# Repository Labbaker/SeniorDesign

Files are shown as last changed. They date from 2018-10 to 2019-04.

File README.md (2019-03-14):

# SeniorDesign
Checklist of things to do:

Main Station Software:
main page: beacon map, view emergency alerts, sidebar w/ new alerts (all pages have back to main menu option)
Map view of beacons - map of the tucson area with icons for each beacon, (gps coords on mouseover? ping on mouseover?) displays if alert triggered or repair needed.
Emergency alerts page: new displayed, resolved on different page
-resolved page: data abt alert
when viewing new alert, text box for message + ack
yes/no for resolving alert

backend stuff: 
Xbee connection - receive GPS data from beacons
XBee connection - get alerts from beacons after the beacons get them from the app
XBee - send ack + message to alert device
Interface with MySQL database?!?! PHP database!?!?!?
pings beacons every hour

Mobile Application:
Main page: buttons for emergencies options, map, "about app" and (about me") - each of these pages has a link back to the main page
About app: just text
map view: pre downloaded map of tucson that will get the user's GPS location and display their location on the map, 
or text that says "outside bounds" if their location ins't on the map. If the phones gps isn't working, get the gpd coords of the nearet
beacon and draw a circle of 20m around that point that says "you're within this circle"
Emergency options: 3 buttons for 3 levels of emergency, yes/no confirm after. 
- these have 4 states: no yes/no (fine), yes, no, no yes/no (not fine) (if rest is finished, add optional text box)
ack screen: "sending" (after hitting button) "sending..." (ack from beacon). (send) ack from main station (text), reset button 
(display note from main station)
About me: (optional) ICE info (medical conditions, contact info)

Beacon Software:
GPS connection: get the beacon's gps, save it. get new coords once every 24 hours, gps should sleep
bluetooth/mobile app: 
(according to adafruit tutorial) broadcasts a char string that mobile app bluetooth looks for
send GPS coords if mobile app requests it for map. 
transmit all the stuff related to alerts/ack'ing them
responds to main station ping every hour

Connections:
Mobile app -> Beacon
Initial Bluetooth connection
Emergency commands
GPS request

Beacon -> Mobile App
Initial Bluetooth connection
Emergency command ack
GPS

Beacon -> Beacon
Mesh Network
Passing GPS
emergency alerts

Beacon -> main station
mesh network connection
ack w/ time and GPS
emergency alerts

main station -> beacon
mesh network
ping request
emergency alert ack w/ note

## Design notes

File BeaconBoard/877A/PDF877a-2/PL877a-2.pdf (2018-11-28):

Linear Technology Corporation
LTC3531ES6-3.3
Parts List | DC877A Rev 2
Item | Qty | Ref - Des | Desc | Manufacturer's Part Number
1 | 2 | C1,C2 | CAP, 0805 22uF 20% 6.3V X5R | TDK C2012X5R0J226M
2 | 1 | C3 | CAP, 0603 1uF 20% 6.3V X5R | AVX 06036D105MAT
3 | 0 | D2 | DIODE, SCHOTTKY BARRIER OPTION | PHILIPS PMEG2010EA OPTION
4 | 1 | JP1 | HEADER,3 PINS 2mm | COMM CON 2802S-03G2
5 | 1 | L1 | INDUCTOR, 10uH | SUMIDA CDRH3D16/HP-100
6 | 1 | R1 | RES, 0402 1M OHMS 5% 1/16W | AAC CR05-105JM
7 | 4 | TP1,TP2,TP3,TP4 | TURRET | MILL MAX2501-2
8 | 1 | U1 | IC, LTC3531ES6-3.3 | LINEAR TECH LTC3531ES6-3.3
9 | 1 | JP1 | SHUNT | COMM CON CCIJ2MM-138G

### 1 of 1

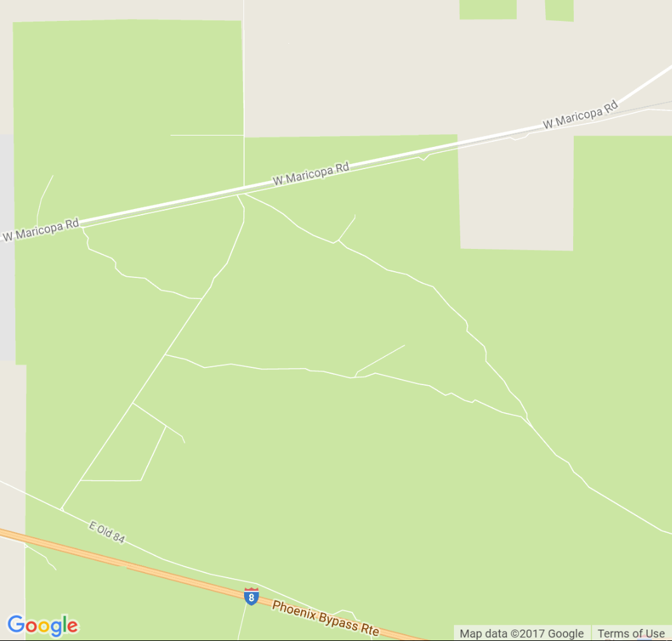
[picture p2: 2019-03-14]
MainStationSoftware/map.png

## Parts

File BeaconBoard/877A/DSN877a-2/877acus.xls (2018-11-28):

Item | Qty | Ref - Des | Desc | Manufacturer's Part Number
 |  | REQUIRED CIRCUIT COMPONENTS:
1 | 2 | C1,C2 | CAP, 0805 22uF 20% 6.3V X5R | TDK C2012X5R0J226M
5 | 1 | L1 | INDUCTOR, 10uH | SUMIDA CDRH3D16/HP-100
8 | 1 | U1 | IC, LTC3531ES6-3.3 | LINEAR TECH LTC3531ES6-3.3
 |  | ADDITIONAL DEMO BOARD CIRCUIT COMPONENTS:
2 | 1 | C3 | CAP, 0603 1uF 20% 6.3V X5R | AVX 06036D105MAT
3 | 0 | D2 | DIODE, SCHOTTKY BARRIER OPTION | PHILIPS PMEG2010EA OPTION
6 | 1 | R1 | RES, 0402 1M OHMS 5% 1/16W | AAC CR05-105JM

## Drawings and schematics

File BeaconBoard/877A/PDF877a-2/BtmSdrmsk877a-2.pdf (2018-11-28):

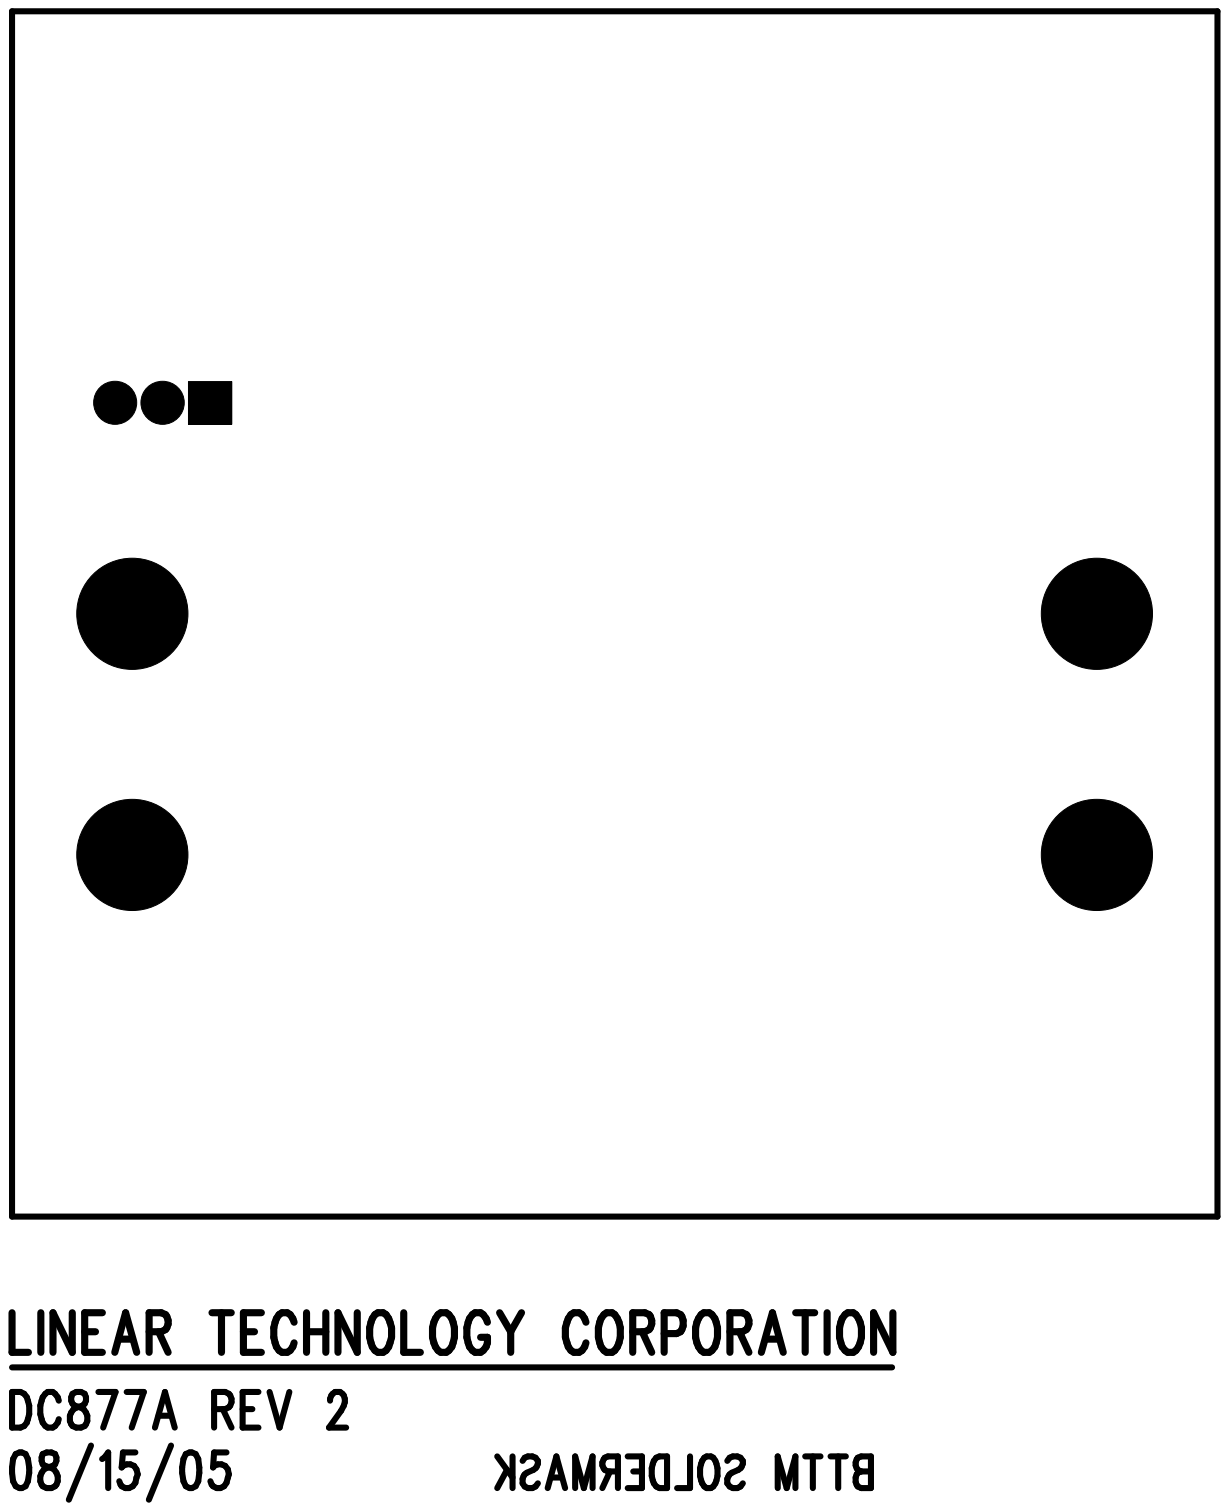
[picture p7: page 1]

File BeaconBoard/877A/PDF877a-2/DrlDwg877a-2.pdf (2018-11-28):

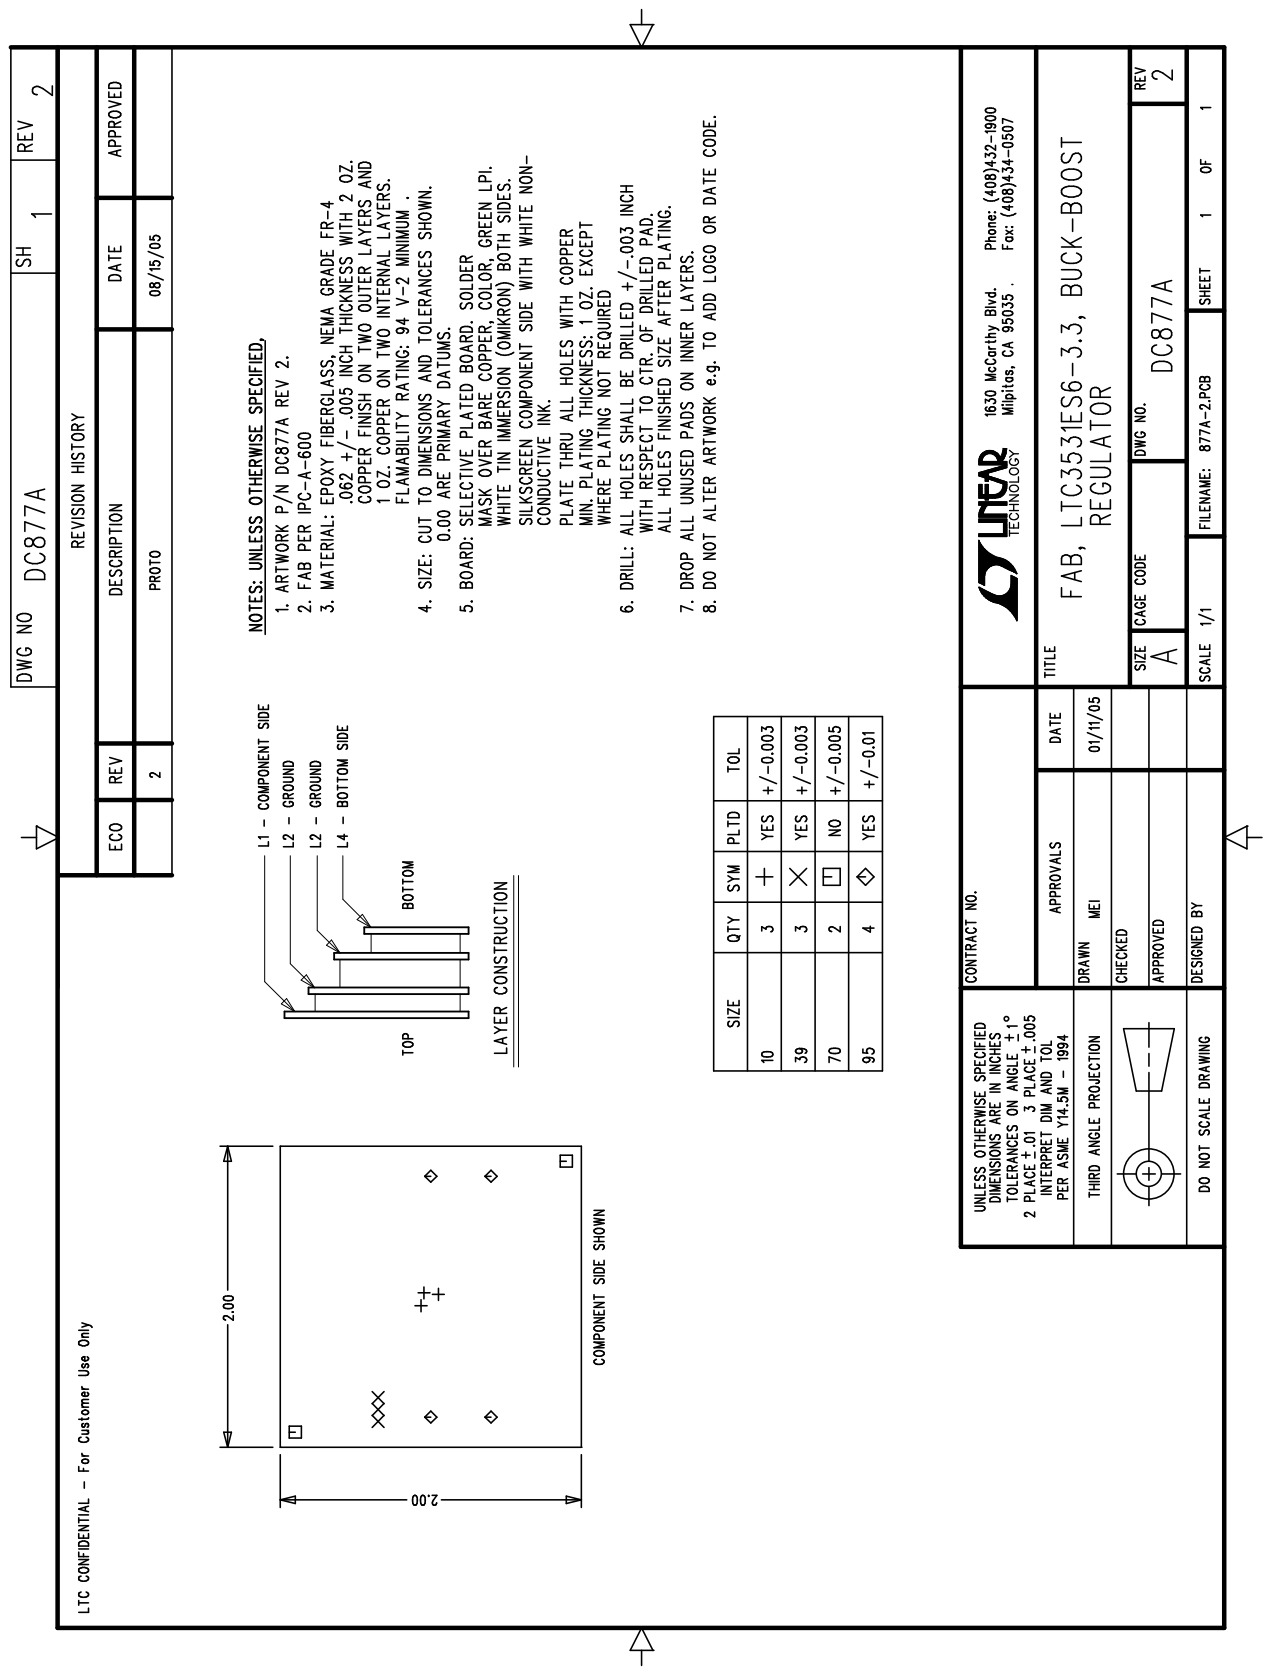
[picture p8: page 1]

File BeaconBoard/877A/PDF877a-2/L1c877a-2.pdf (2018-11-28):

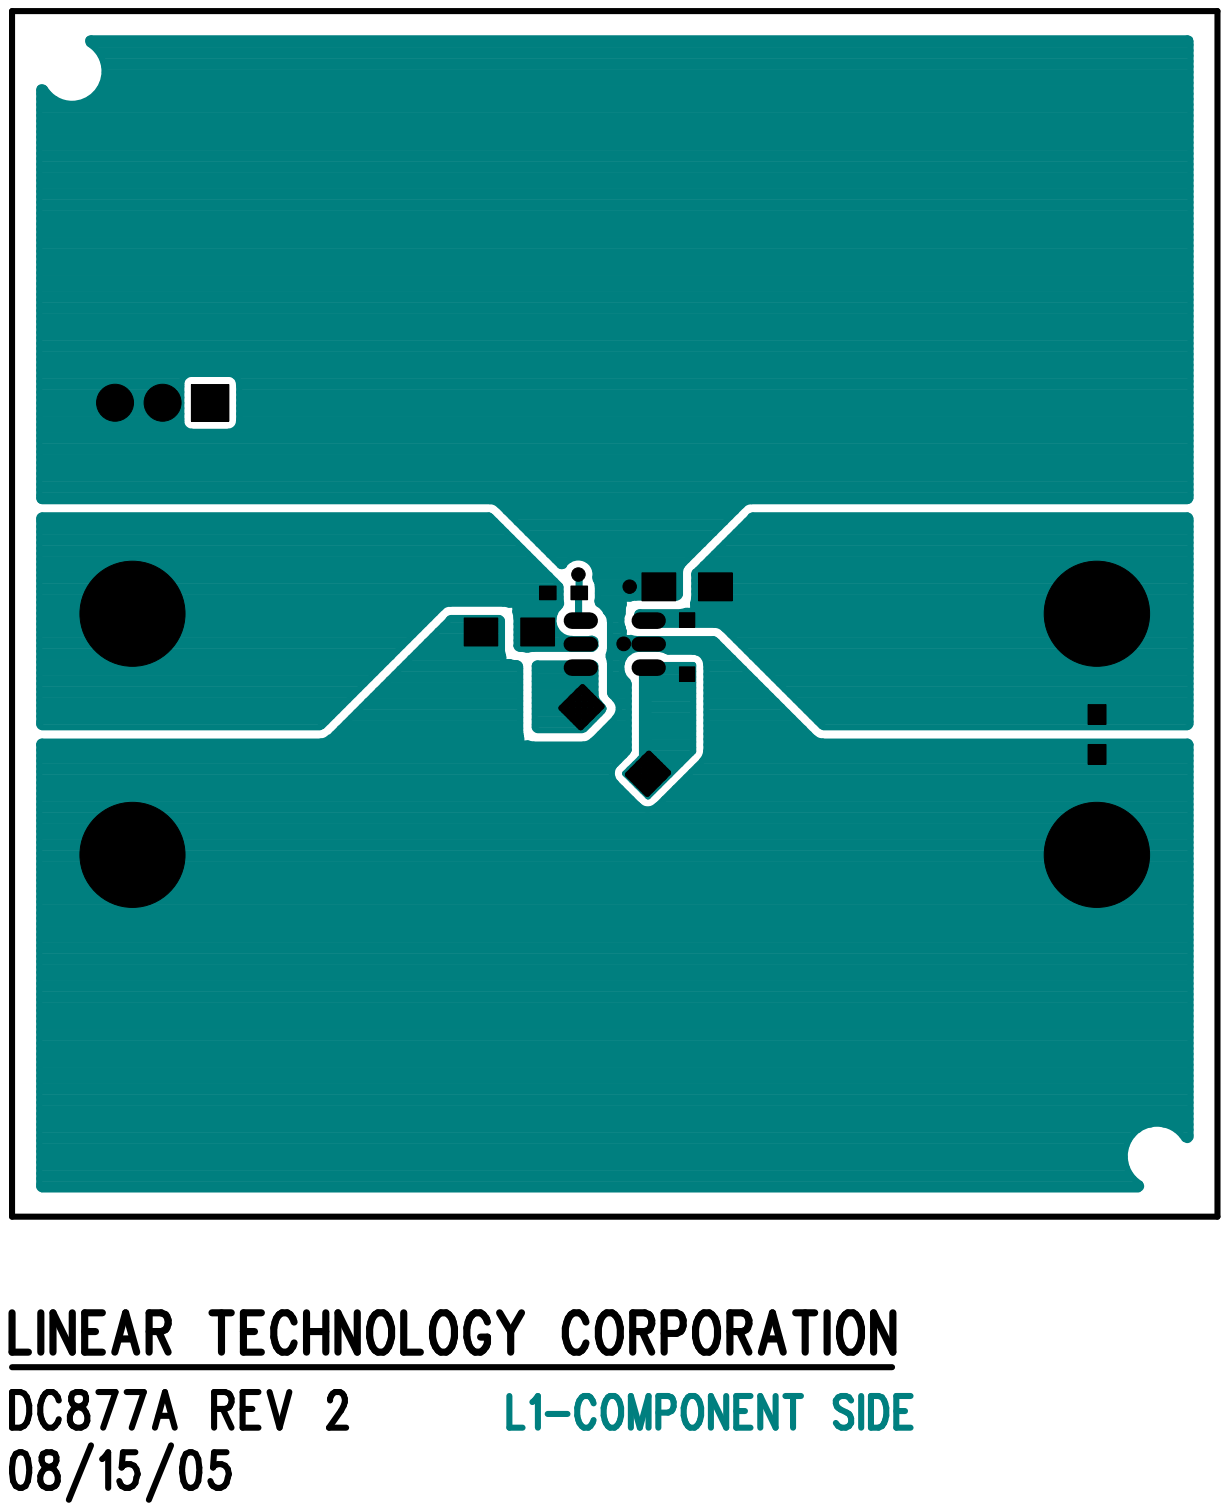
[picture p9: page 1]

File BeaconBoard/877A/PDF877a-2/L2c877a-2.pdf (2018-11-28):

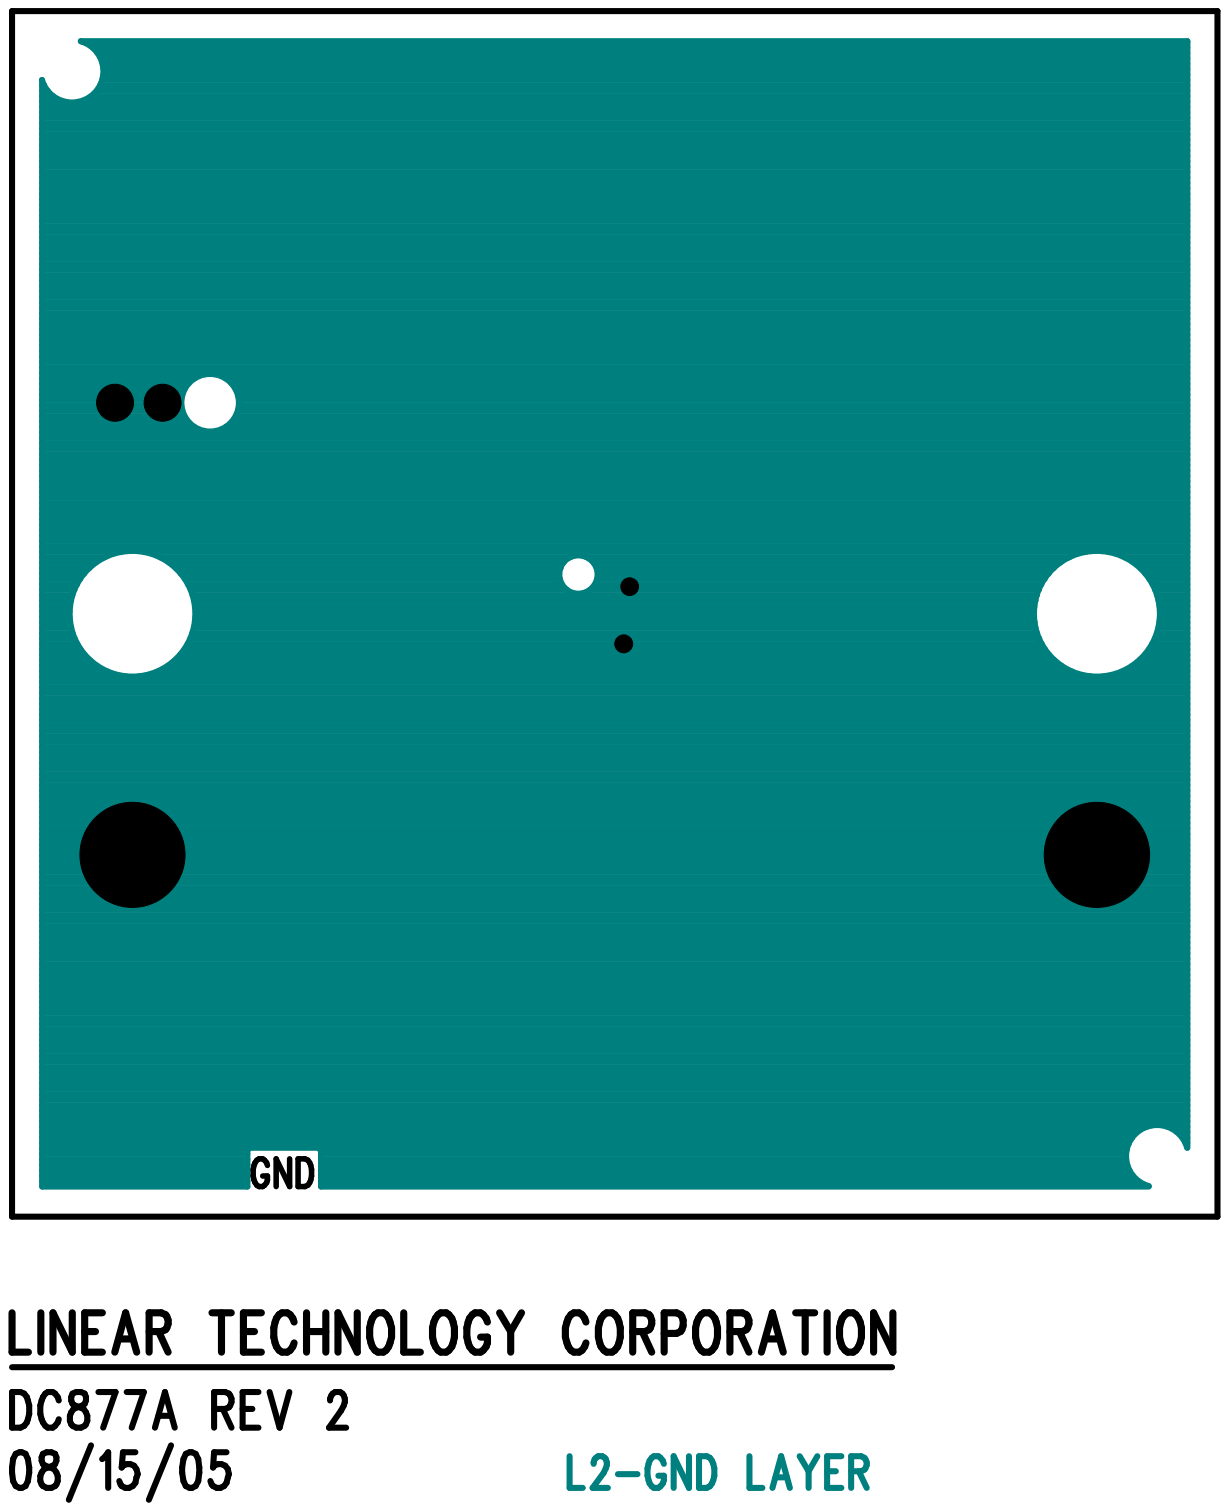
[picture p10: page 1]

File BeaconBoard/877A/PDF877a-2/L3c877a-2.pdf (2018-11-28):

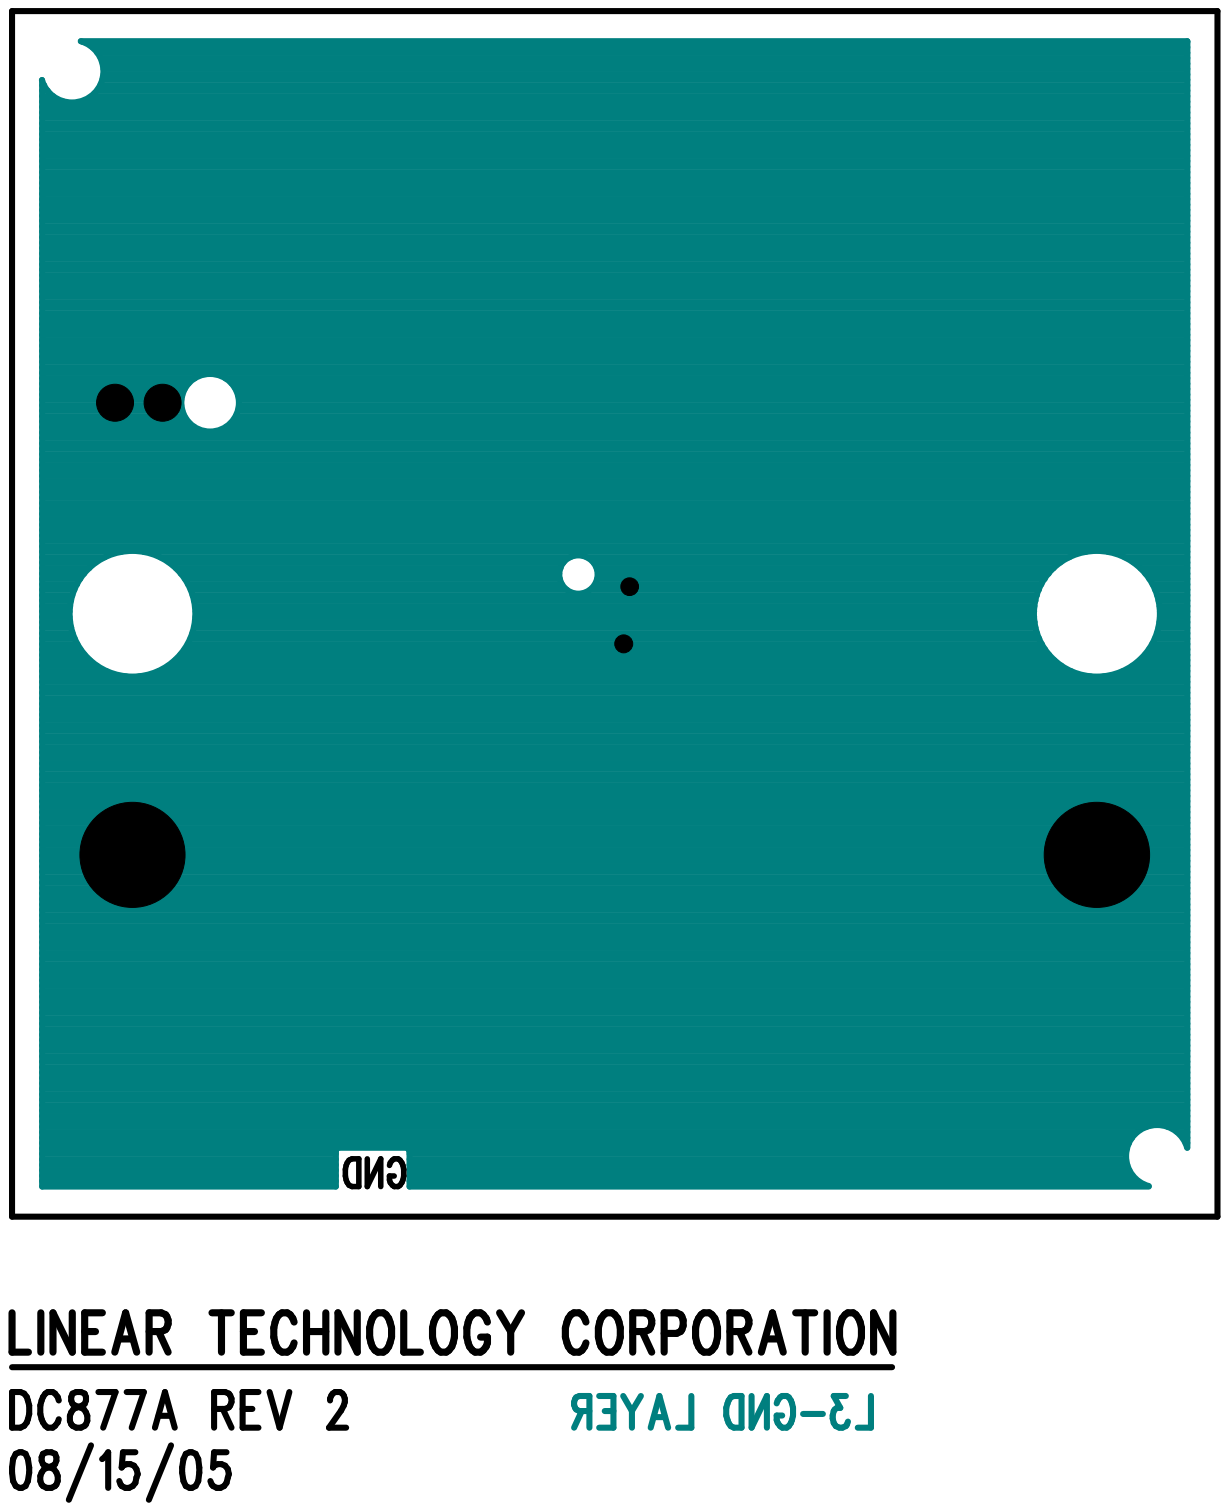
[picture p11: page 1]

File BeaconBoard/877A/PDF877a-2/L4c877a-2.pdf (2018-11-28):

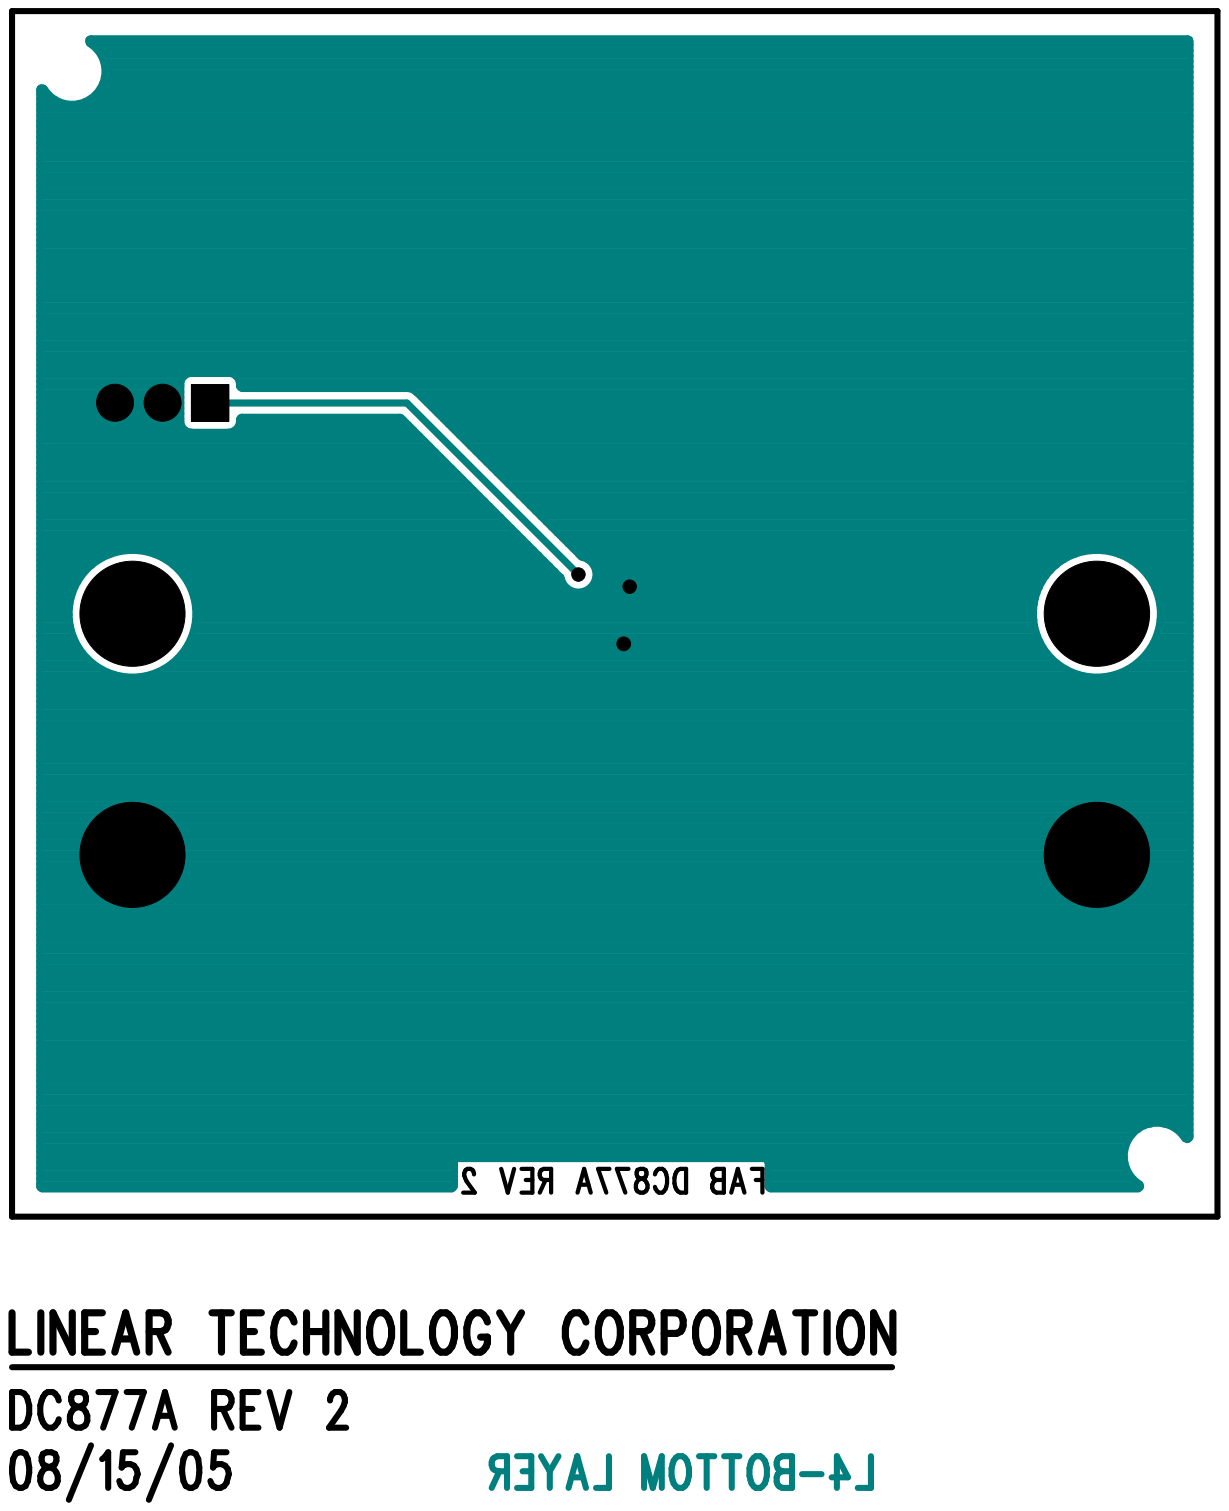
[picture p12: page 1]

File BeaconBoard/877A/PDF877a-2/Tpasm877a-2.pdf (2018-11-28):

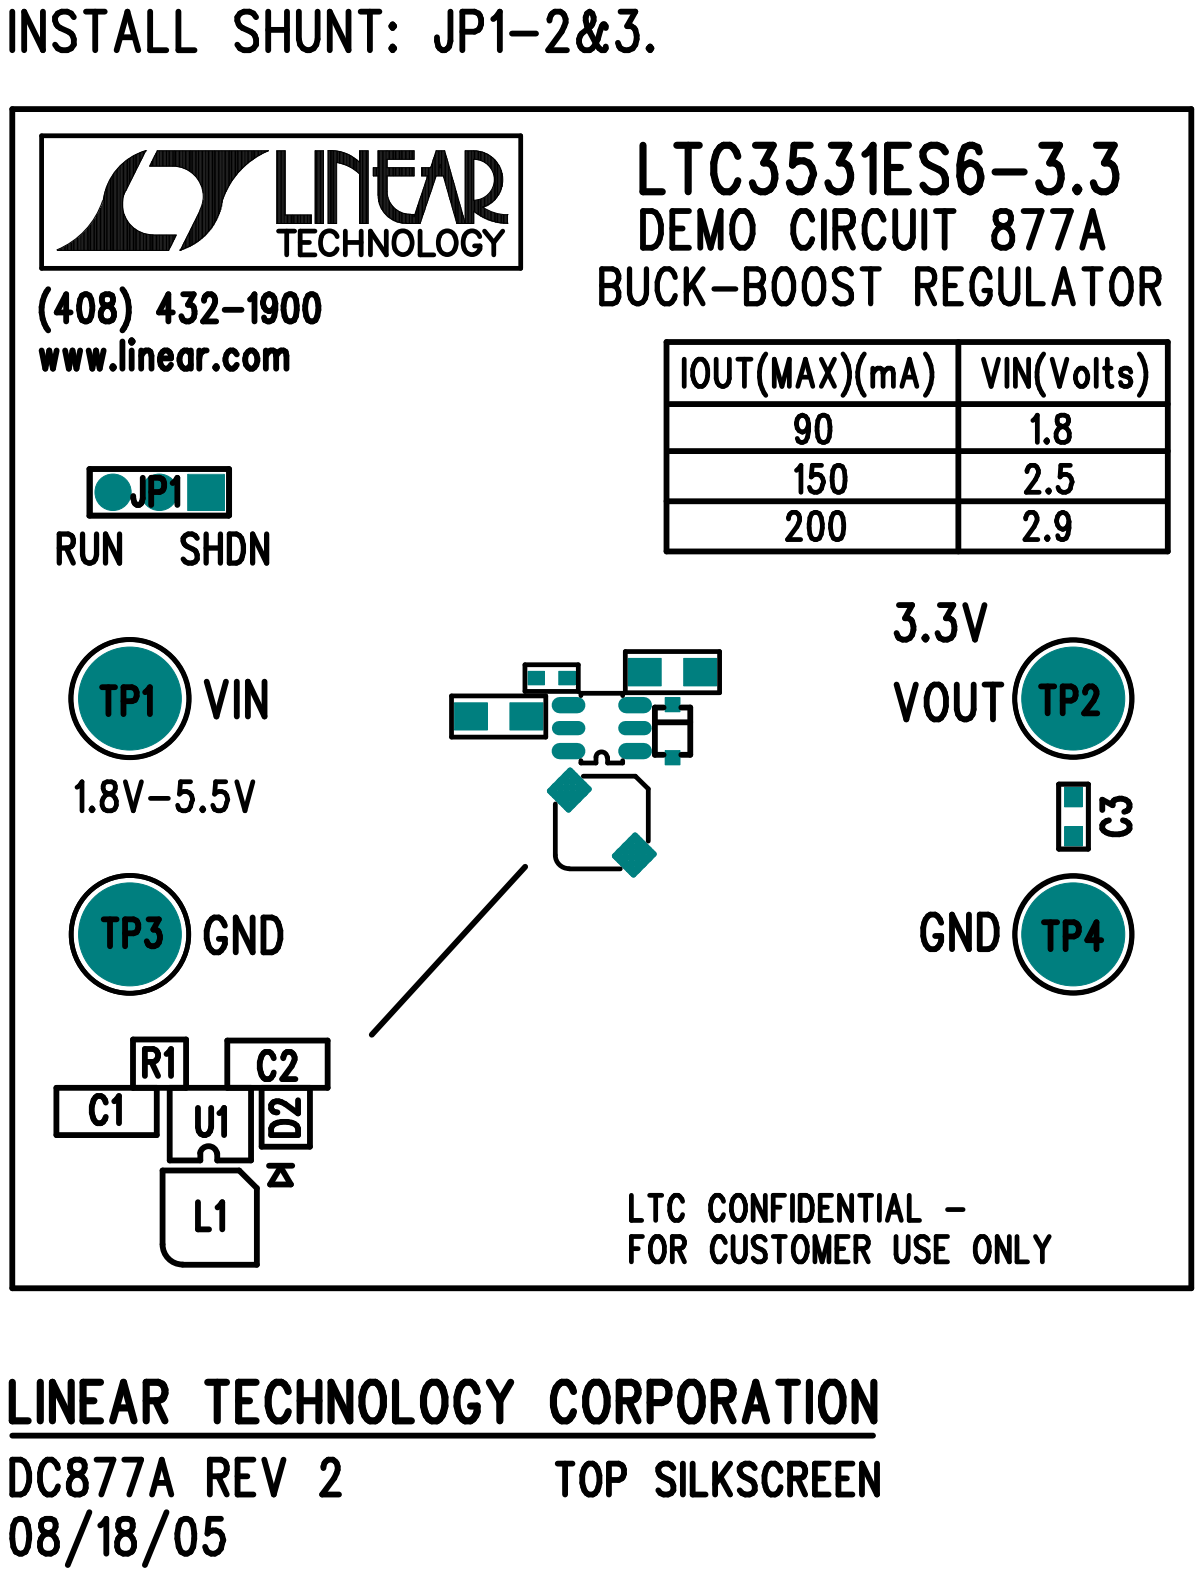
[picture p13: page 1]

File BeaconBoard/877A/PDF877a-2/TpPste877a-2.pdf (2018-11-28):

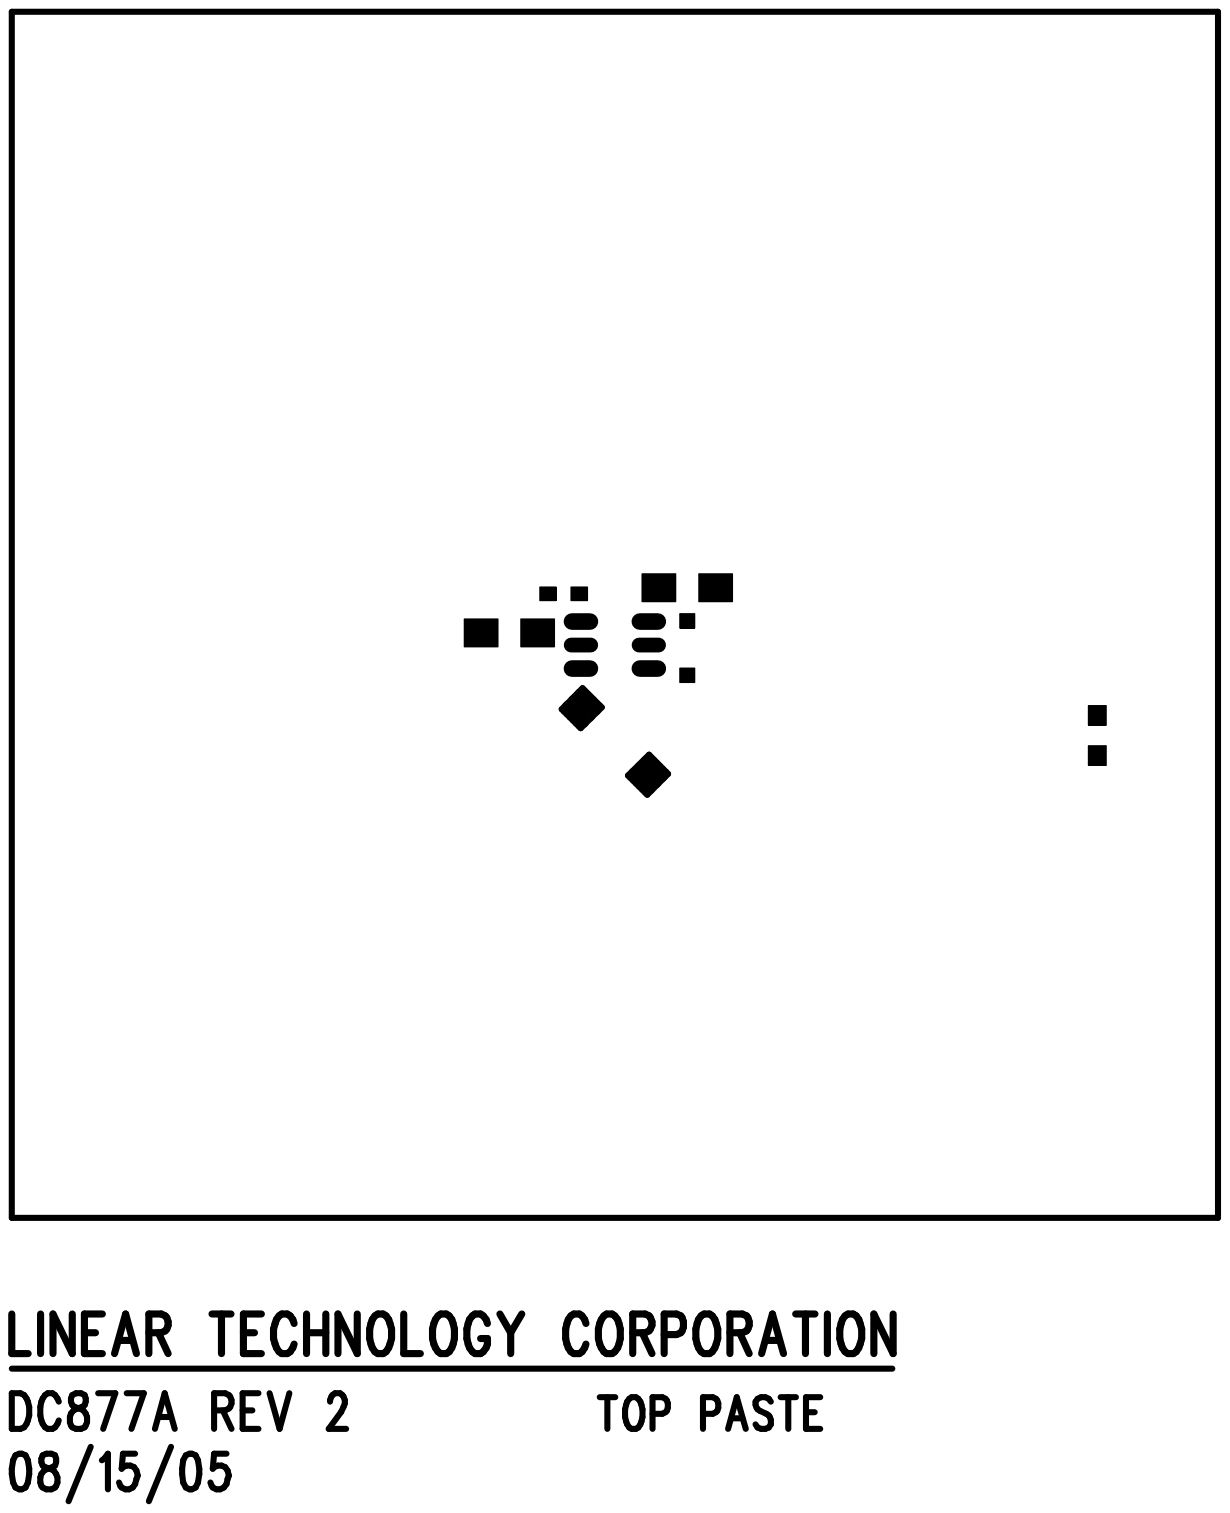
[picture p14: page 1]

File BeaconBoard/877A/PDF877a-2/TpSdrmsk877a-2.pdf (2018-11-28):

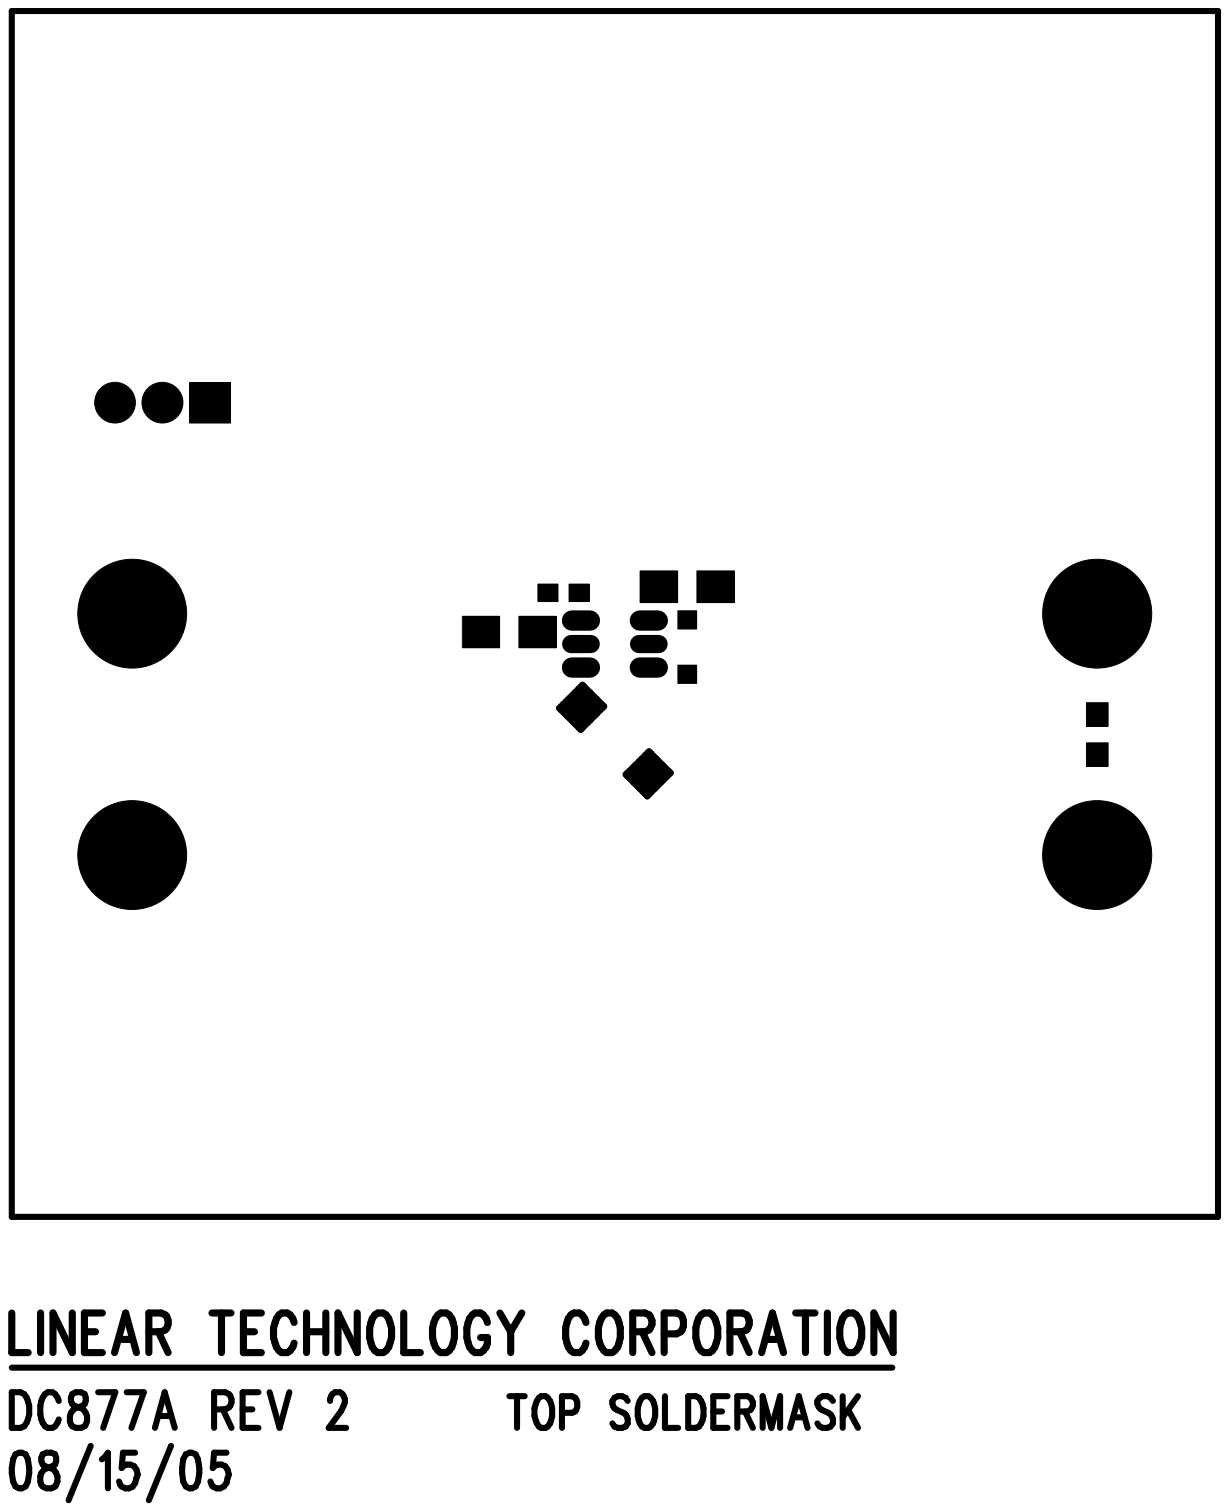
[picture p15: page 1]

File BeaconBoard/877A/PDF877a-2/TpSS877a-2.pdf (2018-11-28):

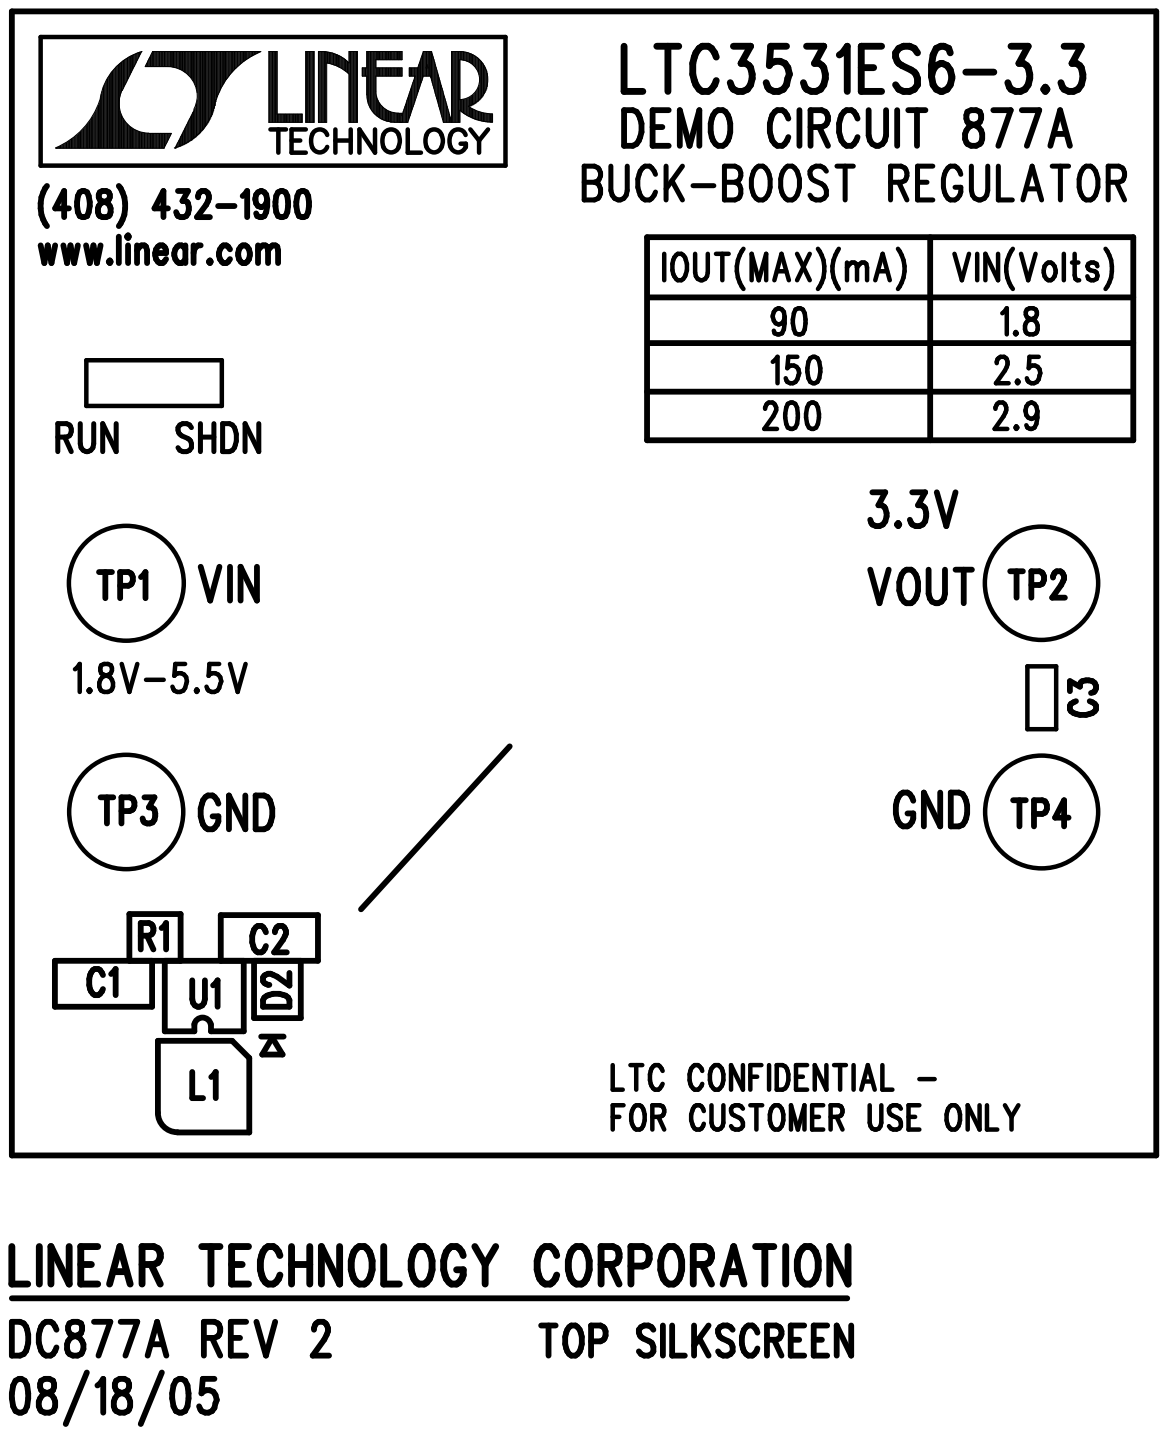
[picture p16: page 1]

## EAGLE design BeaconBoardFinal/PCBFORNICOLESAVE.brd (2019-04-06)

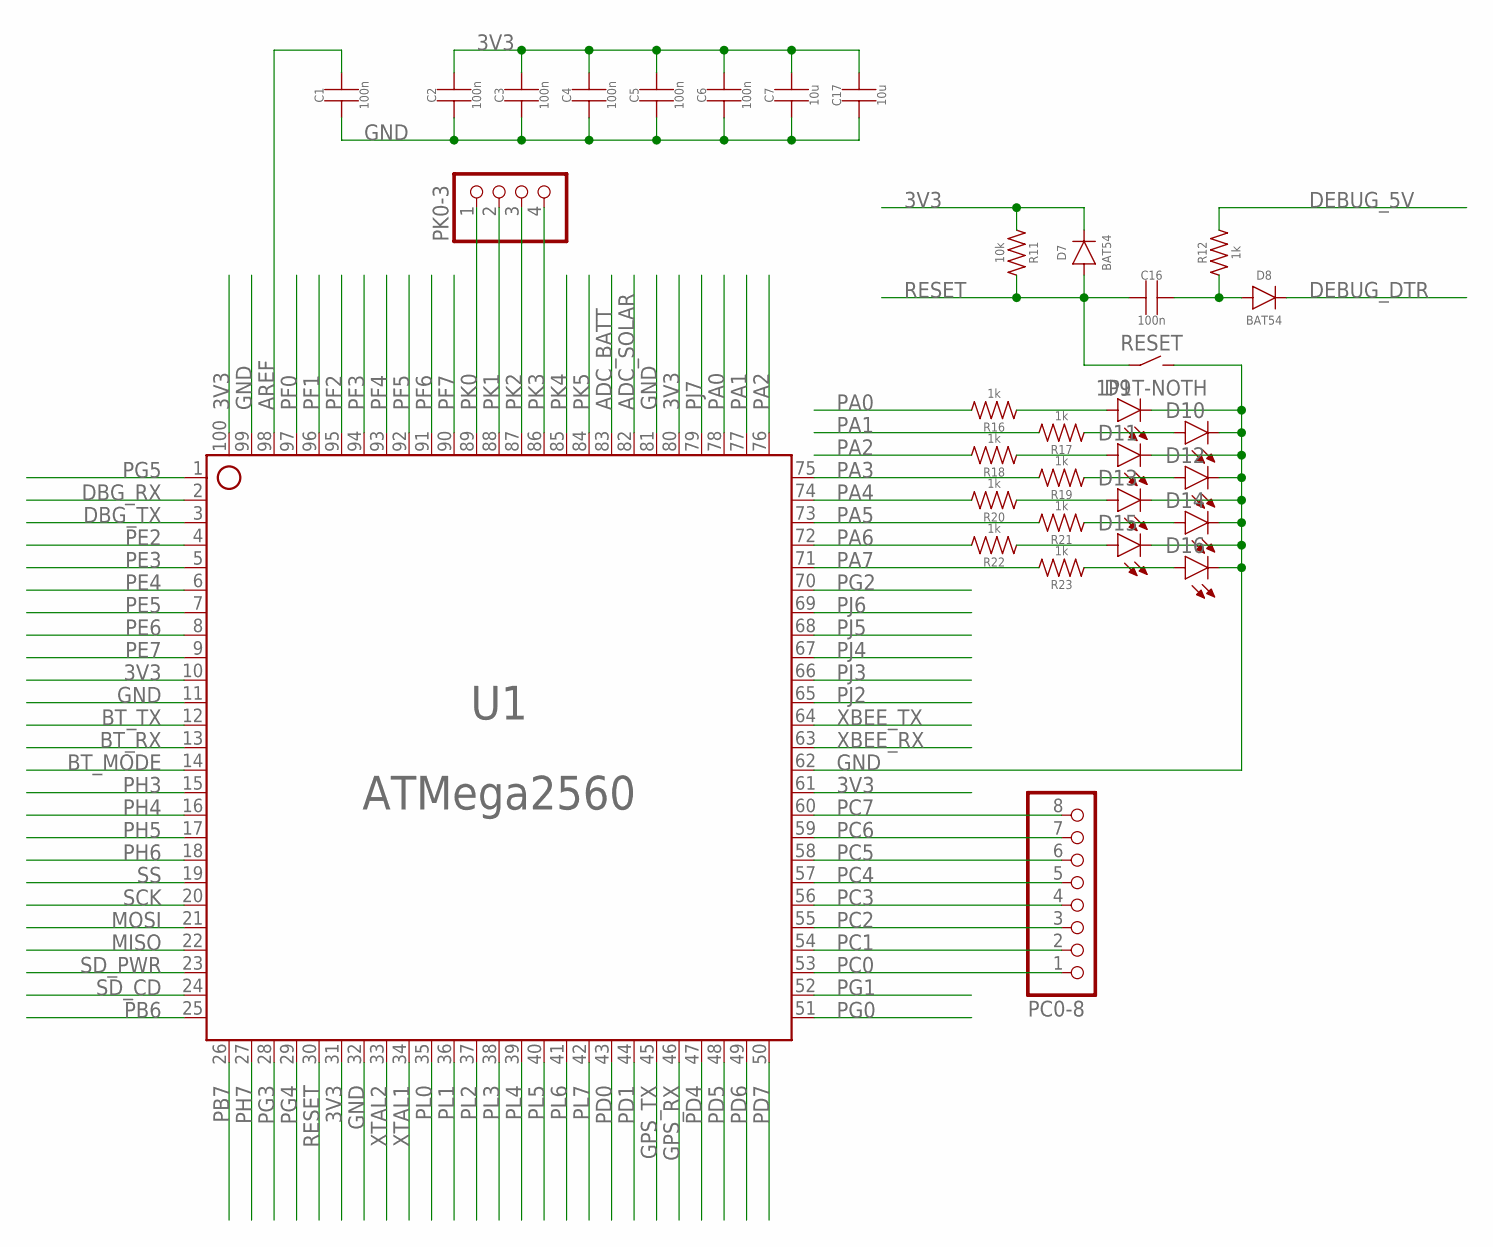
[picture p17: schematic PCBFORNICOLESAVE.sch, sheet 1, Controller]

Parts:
C1, C2, C3, C4, C5, C6, C16: 100n; 0603
C7, C17: 10u; 1206
D7, D8: BAT54; SOD323
D9, D10, D11, D12, D13, D14, D15, D16: LED1206; 1206
PC0-8: PINHD-1X82MM; 1X08_2MM
PK0-3: PINHD-1X42MM; 1X04_2MM
R11: 10k; 0603
R12, R16, R17, R18, R19, R20, R21, R22, R23: 1k; 0603
RESET: 1P1T-NOTH; 6X6MM-TH
U1: ATMega2560; 100QFP

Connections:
3V3: C2.1, C3.1, C4.1, C5.1, C6.1, C7.1, C17.1, D7.2 (C), R11.2, U1.10, U1.31, U1.61, U1.80, U1.100; also elsewhere on the board
ADC_BATT: U1.83; also elsewhere on the board
ADC_SOLAR: U1.82; also elsewhere on the board
AREF: C1.1, U1.98
BT_MODE: U1.14; also elsewhere on the board
BT_RX: U1.13; also elsewhere on the board
BT_TX: U1.12; also elsewhere on the board
DBG_RX: U1.2; also elsewhere on the board
DBG_TX: U1.3; also elsewhere on the board
DEBUG_5V: R12.1; also elsewhere on the board
DEBUG_DTR: D8.2 (C); also elsewhere on the board
GND: C1.2, C2.2, C3.2, C4.2, C5.2, C6.2, C7.2, C17.2, D9.2 (C), D10.2 (C), D11.2 (C), D12.2 (C), D13.2 (C), D14.2 (C), D15.2 (C), D16.2 (C), RESET.3 (A1), RESET.4 (A1), U1.11, U1.32, U1.62, U1.81, U1.99; also elsewhere on the board
GPS_RX: U1.46; also elsewhere on the board
GPS_TX: U1.45; also elsewhere on the board
MISO: U1.22; also elsewhere on the board
MOSI: U1.21; also elsewhere on the board
unnamed: C16.1, D8.1 (A), R12.2
unnamed: D9.1 (A), R16.2
unnamed: D10.1 (A), R17.2
unnamed: D11.1 (A), R18.2
unnamed: D12.1 (A), R19.2
unnamed: D13.1 (A), R20.2
unnamed: D14.1 (A), R21.2
unnamed: D15.1 (A), R22.2
unnamed: D16.1 (A), R23.2
PA0: R16.1, U1.78
PA1: R17.1, U1.77
PA2: R18.1, U1.76
PA3: R19.1, U1.75
PA4: R20.1, U1.74
PA5: R21.1, U1.73
PA6: R22.1, U1.72
PA7: R23.1, U1.71
PB6: U1.25
PB7: U1.26
PC0: PC0-8.1, U1.53
PC1: PC0-8.2, U1.54
PC2: PC0-8.3, U1.55
PC3: PC0-8.4, U1.56
PC4: PC0-8.5, U1.57
PC5: PC0-8.6, U1.58
PC6: PC0-8.7, U1.59
PC7: PC0-8.8, U1.60
PD0: U1.43
PD1: U1.44
PD4: U1.47
PD5: U1.48
PD6: U1.49
PD7: U1.50
PE2: U1.4
PE3: U1.5
PE4: U1.6
PE5: U1.7
PE6: U1.8
PE7: U1.9
PF0: U1.97
PF1: U1.96
PF2: U1.95
PF3: U1.94
PF4: U1.93
PF5: U1.92
PF6: U1.91
PF7: U1.90
PG0: U1.51
PG1: U1.52
PG2: U1.70
PG3: U1.28
PG4: U1.29
PG5: U1.1
PH3: U1.15
PH4: U1.16
PH5: U1.17
PH6: U1.18
PH7: U1.27
PJ2: U1.65
PJ3: U1.66
PJ4: U1.67
PJ5: U1.68
PJ6: U1.69
PJ7: U1.79
PK0: PK0-3.1, U1.89
PK1: PK0-3.2, U1.88
PK2: PK0-3.3, U1.87
PK3: PK0-3.4, U1.86
PK4: U1.85
PK5: U1.84
PL0: U1.35
PL1: U1.36
PL2: U1.37
PL3: U1.38
PL4: U1.39
PL5: U1.40
PL6: U1.41
PL7: U1.42
RESET: C16.2, D7.1 (A), R11.1, RESET.1, RESET.2 (P1), U1.30; also elsewhere on the board
SCK: U1.20; also elsewhere on the board
SD_CD: U1.24; also elsewhere on the board
SD_PWR: U1.23; also elsewhere on the board
SS: U1.19; also elsewhere on the board
XBEE_RX: U1.63; also elsewhere on the board
XBEE_TX: U1.64; also elsewhere on the board
XTAL1: U1.34
XTAL2: U1.33

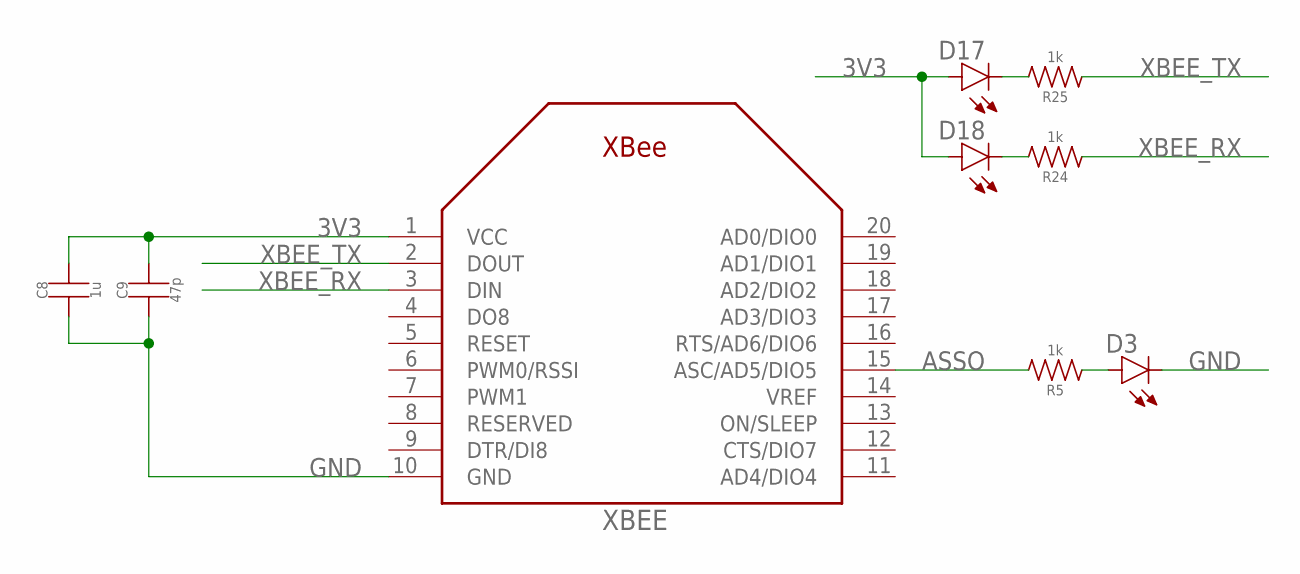
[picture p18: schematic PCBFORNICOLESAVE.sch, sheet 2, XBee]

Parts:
C8: 1u; 0603
C9: 47p; 0603
D3, D17, D18: LED1206; 1206
R5, R24, R25: 1k; 0603
XBEE: XBEE

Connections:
3V3: C8.1, C9.1, D17.1 (A), D18.1 (A), XBEE.1 (VCC); also elsewhere on the board
ASSO: R5.1, XBEE.15 (ASC/AD5/DIO5)
GND: C8.2, C9.2, D3.2 (C), XBEE.10 (GND); also elsewhere on the board
unnamed: D3.1 (A), R5.2
unnamed: D17.2 (C), R25.1
unnamed: D18.2 (C), R24.1
XBEE_RX: R24.2, XBEE.3 (DIN); also elsewhere on the board
XBEE_TX: R25.2, XBEE.2 (DOUT); also elsewhere on the board

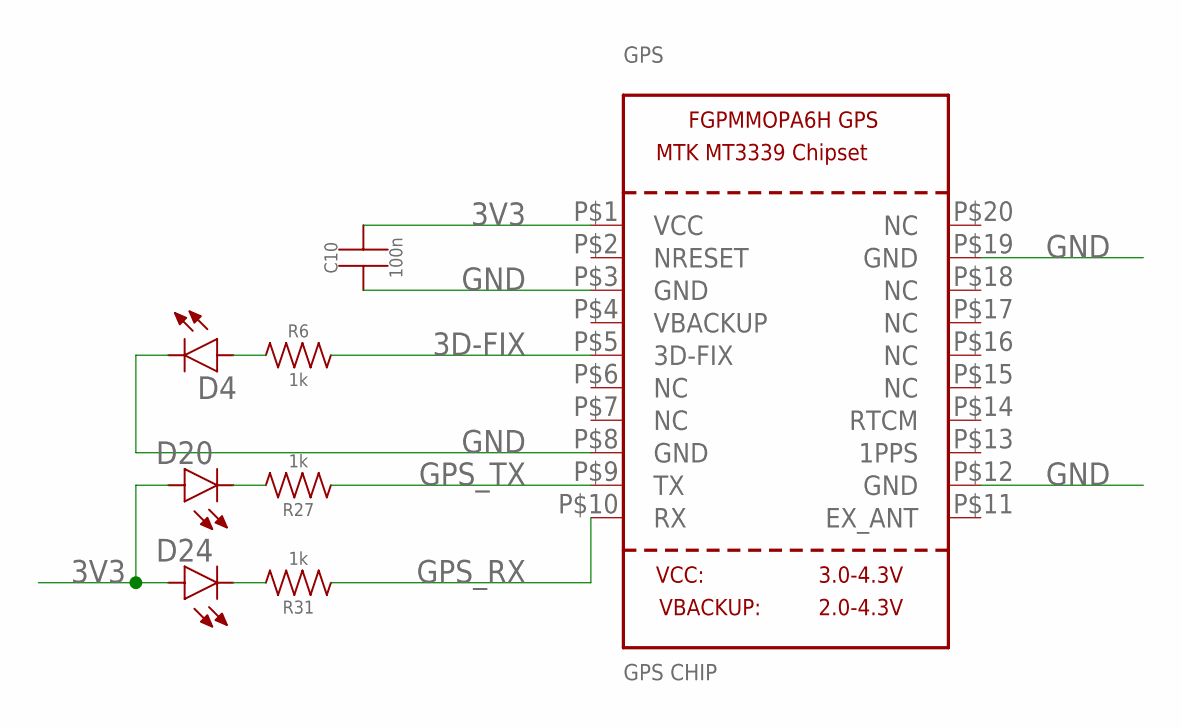
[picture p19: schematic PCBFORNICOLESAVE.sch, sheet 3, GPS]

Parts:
C10: 100n; 0603
D4, D20, D24: LED1206; 1206
GPS: GPS CHIP; FGPMMOPA6H
R6, R27, R31: 1k; 0603

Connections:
3D-FIX: GPS.P$5 (3D-FIX), R6.1
3V3: C10.1, D20.1 (A), D24.1 (A), GPS.P$1 (VCC); also elsewhere on the board
GND: C10.2, D4.2 (C), GPS.P$3 (GND), GPS.P$8 (GND), GPS.P$12 (GND), GPS.P$19 (GND); also elsewhere on the board
GPS_RX: GPS.P$10 (RX), R31.2; also elsewhere on the board
GPS_TX: GPS.P$9 (TX), R27.2; also elsewhere on the board
unnamed: D4.1 (A), R6.2
unnamed: D20.2 (C), R27.1
unnamed: D24.2 (C), R31.1

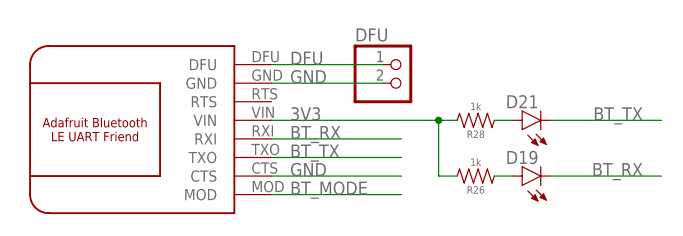
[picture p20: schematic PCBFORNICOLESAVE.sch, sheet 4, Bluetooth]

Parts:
BT: ADAFRUIT_BLUETOOTH_LE_UART_FRIEND
D19, D21: LED1206; 1206
DFU: PINHD-1X2""; 1X02
R26, R28: 1k; 0603

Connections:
3V3: BT.VIN, R26.1, R28.1; also elsewhere on the board
BT_MODE: BT.MOD; also elsewhere on the board
BT_RX: BT.RXI, D19.2 (C); also elsewhere on the board
BT_TX: BT.TXO, D21.2 (C); also elsewhere on the board
DFU: BT.DFU, DFU.1
GND: BT.CTS, BT.GND, DFU.2; also elsewhere on the board
unnamed: D21.1 (A), R28.2
unnamed: D19.1 (A), R26.2

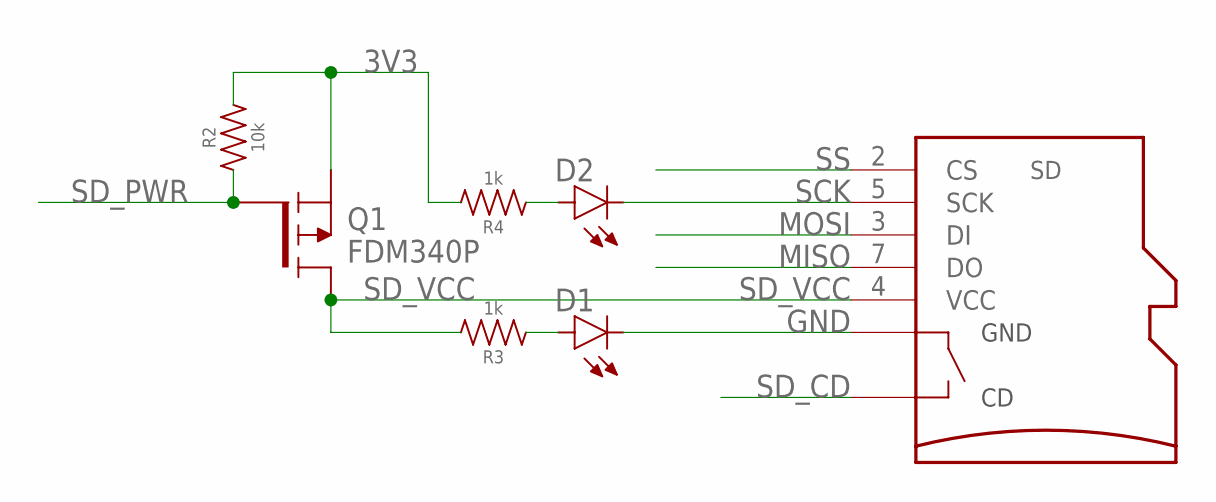
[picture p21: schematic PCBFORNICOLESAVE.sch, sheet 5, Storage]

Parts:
D1, D2: LED1206; 1206
Q1: FDM340P; SOT23-3
R2: 10k; 0603
R3, R4: 1k; 0603
SD: MICROSDFRONT; USD,FRONT

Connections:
3V3: Q1.3 (S), R2.1, R4.1; also elsewhere on the board
GND: D1.2 (C), SD.1 (GND), SD.6 (GND), SD.8 (GND), SD.S0 (GND), SD.S1 (GND), SD.S2 (GND), SD.S3 (GND); also elsewhere on the board
MISO: SD.7 (DO); also elsewhere on the board
MOSI: SD.3 (DI); also elsewhere on the board
unnamed: D1.1 (A), R3.2
unnamed: D2.1 (A), R4.2
SCK: D2.2 (C), SD.5 (SCK); also elsewhere on the board
SD_CD: SD.SW (CD); also elsewhere on the board
SD_PWR: Q1.1 (G), R2.2; also elsewhere on the board
SD_VCC: Q1.5 (D), R3.1, SD.4 (VCC)
SS: SD.2 (CS); also elsewhere on the board

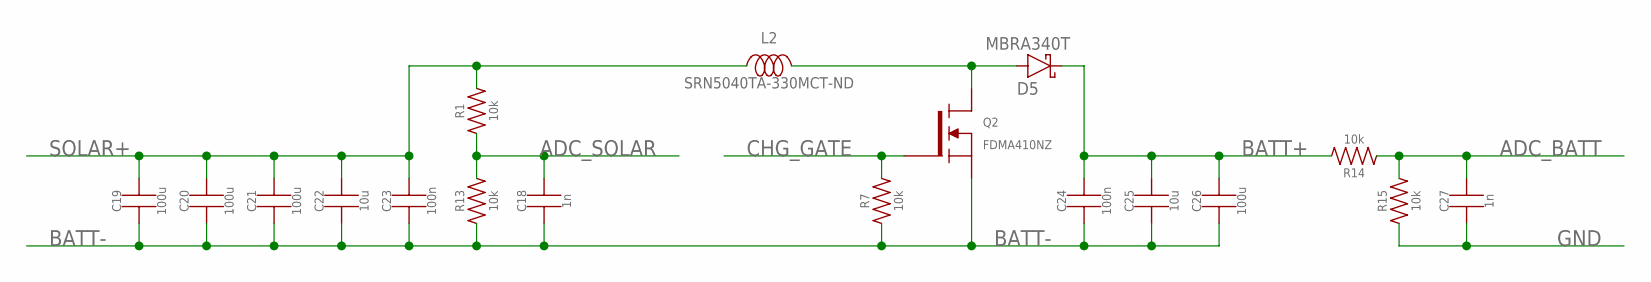
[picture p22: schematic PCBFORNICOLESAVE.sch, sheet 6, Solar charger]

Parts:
C18, C27: 1n; 0603
C19, C20, C21, C26: 100u; 1206
C22, C25: 10u; 1206
C23, C24: 100n; 0603
D5: MBRA340T; DO214AC
L2: SRN5040TA-330MCT-ND; 2020
Q2: FDMA410NZ; WDFN-6
R1, R7, R13, R14, R15: 10k; 0603

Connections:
ADC_BATT: C27.1, R14.2, R15.1; also elsewhere on the board
ADC_SOLAR: C18.1, R1.2, R13.1; also elsewhere on the board
BATT+: C24.1, C25.1, C26.1, D5.2 (C), R14.1; also elsewhere on the board
BATT-: C18.2, C19.2, C20.2, C21.2, C22.2, C23.2, C24.2, C25.2, C26.2, Q2.4 (S), Q2.S, R7.2, R13.2; also elsewhere on the board
CHG_GATE: Q2.3 (G), R7.1
GND: C27.2, R15.2; also elsewhere on the board
unnamed: D5.1 (A), L2.2, Q2.1 (D), Q2.2 (D), Q2.5 (D), Q2.6 (D), Q2.PAD (D)
SOLAR+: C19.1, C20.1, C21.1, C22.1, C23.1, L2.1, R1.1; also elsewhere on the board

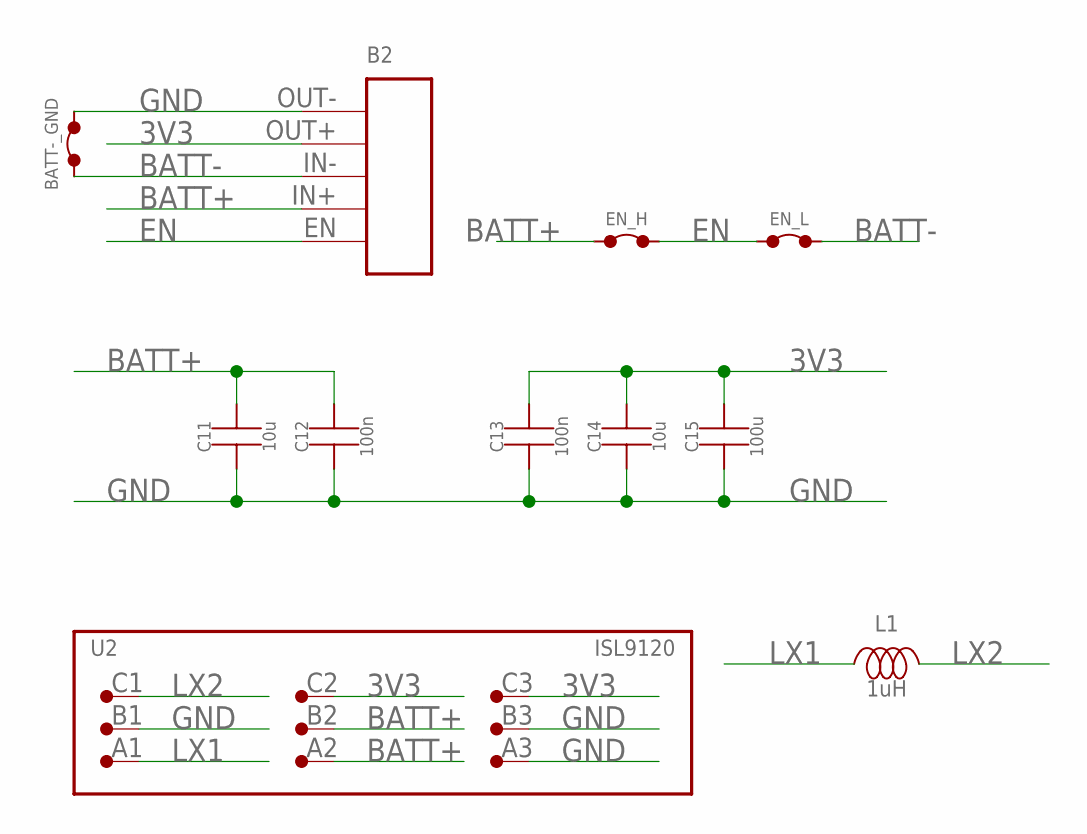
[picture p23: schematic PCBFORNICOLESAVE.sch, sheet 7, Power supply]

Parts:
B2: 5X1BUCK-BOOST; UNBRANDED_BUCK-BOOST
BATT-_GND: JUMPERHC_30V; JUMPER_HC_30V
C11, C14: 10u; 1206
C12, C13: 100n; 0603
C15: 100u; 1206
EN_H: JUMPER30V; JUMPER_30V
EN_L: JUMPER30V; JUMPER_30V
L1: 1uH; 1008
U2: ISL9120; 3X3X0.4BGA

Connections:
3V3: B2.OUT+, C13.1, C14.1, C15.1, U2.C2, U2.C3; also elsewhere on the board
BATT+: B2.IN+, C11.1, C12.1, EN_H.1, U2.A2, U2.B2; also elsewhere on the board
BATT-: B2.IN-, BATT-_GND.1, EN_L.2; also elsewhere on the board
EN: B2.EN, EN_H.2, EN_L.1
GND: B2.OUT-, BATT-_GND.2, C11.2, C12.2, C13.2, C14.2, C15.2, U2.A3, U2.B1, U2.B3; also elsewhere on the board
LX1: L1.1, U2.A1
LX2: L1.2, U2.C1

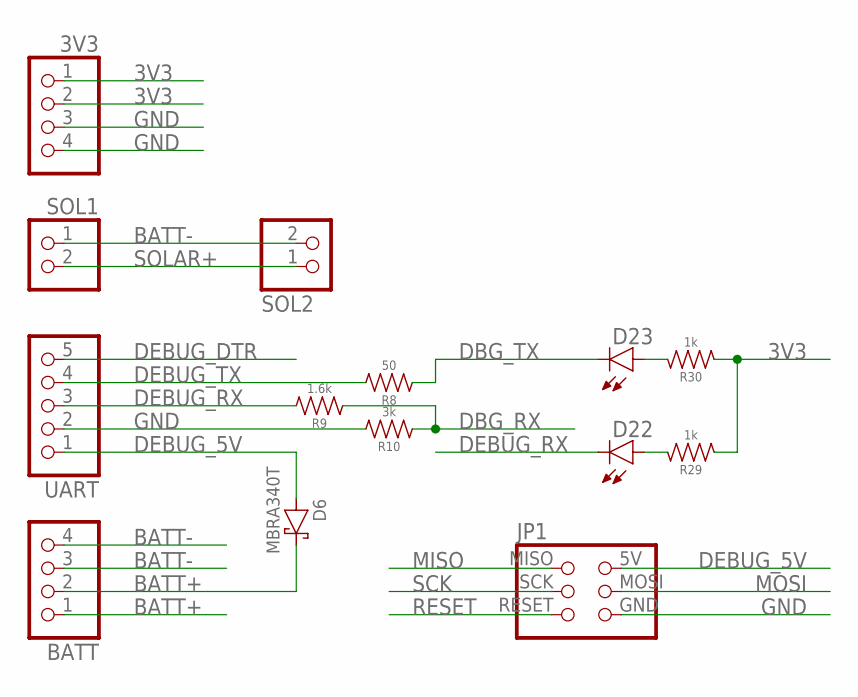
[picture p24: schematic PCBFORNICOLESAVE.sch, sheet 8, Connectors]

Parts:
3V3: PINHD-1X4RH; 1X04
BATT: PINHD-1X490RH; 1X04/90
D6: MBRA340T; DO214AC
D22, D23: LED1206; 1206
JP1: PINHD-2X3ISP; 2X03_ISP
R8: 50; 0603
R9: 1.6k; 0603
R10: 3k; 0603
R29, R30: 1k; 0603
SOL1, SOL2: PINHD-1X2/90; 1X02/90
UART: PINHD-1X590RH; 1X05/90

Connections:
3V3: 3V3.1, 3V3.2, R29.1, R30.1; also elsewhere on the board
BATT+: BATT.1, BATT.2, D6.2 (C); also elsewhere on the board
BATT-: BATT.3, BATT.4, SOL1.1, SOL2.2; also elsewhere on the board
DBG_RX: R9.2, R10.2; also elsewhere on the board
DBG_TX: D23.2 (C), R8.2; also elsewhere on the board
DEBUG_5V: D6.1 (A), JP1.5V (2), UART.1; also elsewhere on the board
DEBUG_DTR: UART.5; also elsewhere on the board
DEBUG_RX: D22.2 (C), R9.1, UART.3
DEBUG_TX: R8.1, UART.4
GND: 3V3.3, 3V3.4, JP1.GND (6), R10.1, UART.2; also elsewhere on the board
MISO: JP1.MISO (1); also elsewhere on the board
MOSI: JP1.MOSI (4); also elsewhere on the board
unnamed: D23.1 (A), R30.2
unnamed: D22.1 (A), R29.2
RESET: JP1.RESET (5); also elsewhere on the board
SCK: JP1.SCK (3); also elsewhere on the board
SOLAR+: SOL1.2, SOL2.1; also elsewhere on the board

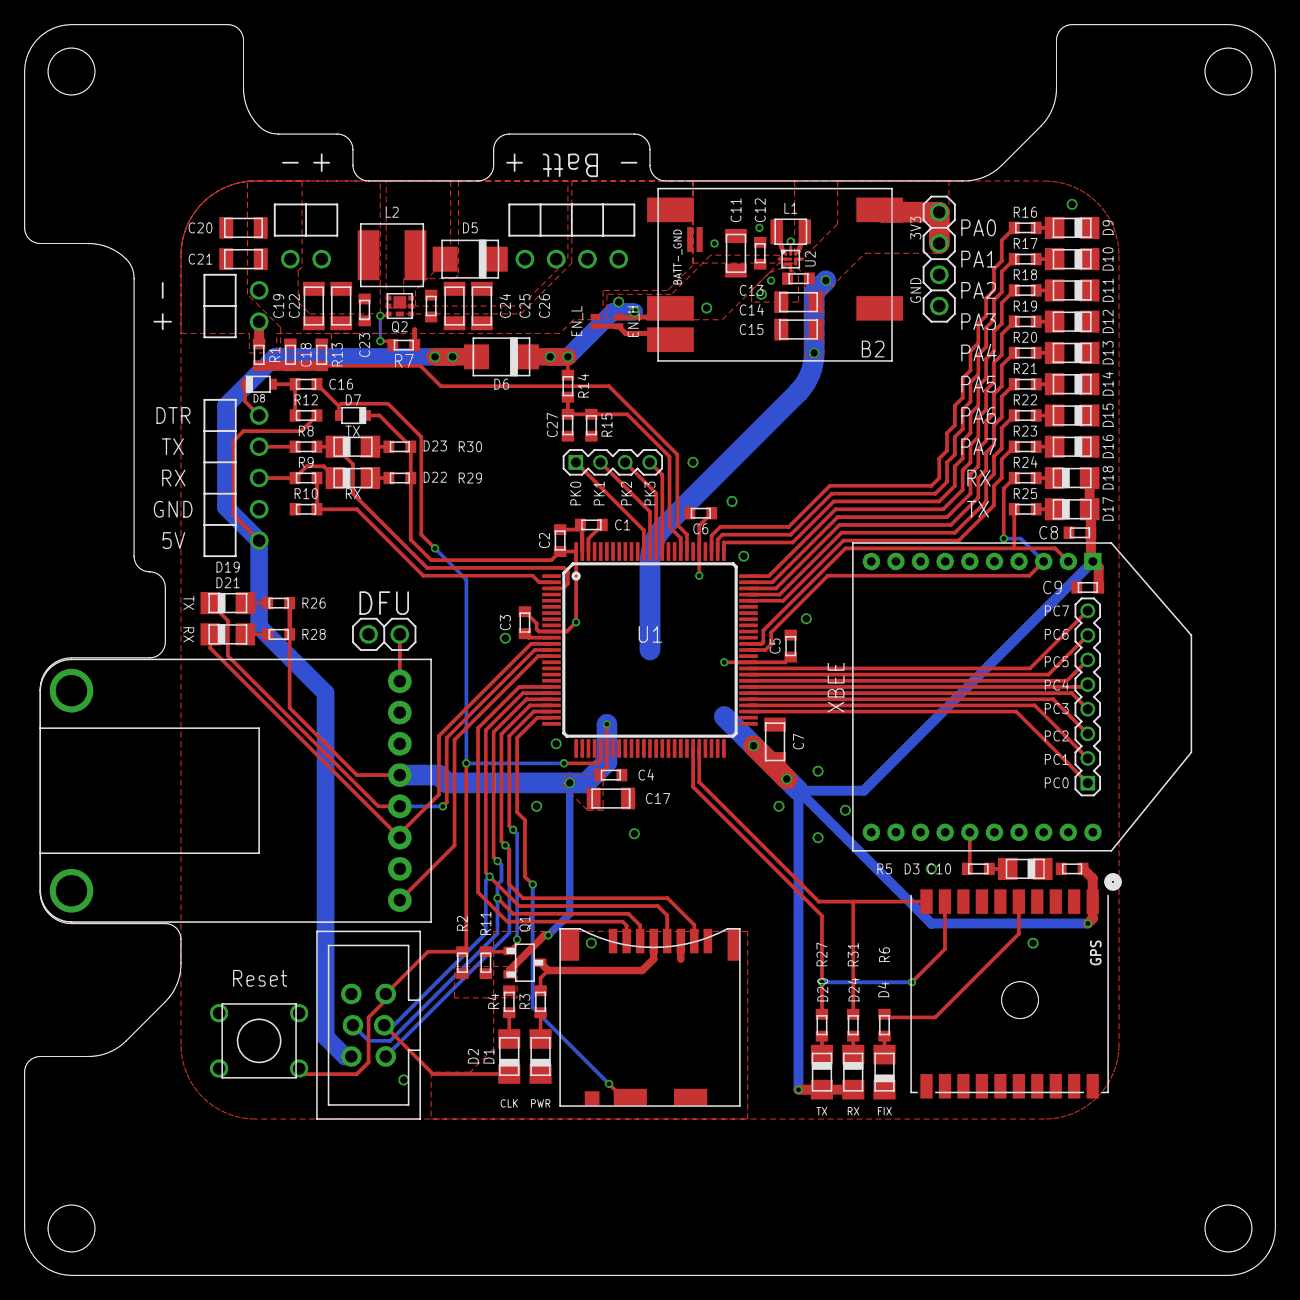
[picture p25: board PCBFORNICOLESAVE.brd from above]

Board: 2 copper layers, 101.6 x 101.6 mm, 106 parts (0 on the bottom side), 78 nets.

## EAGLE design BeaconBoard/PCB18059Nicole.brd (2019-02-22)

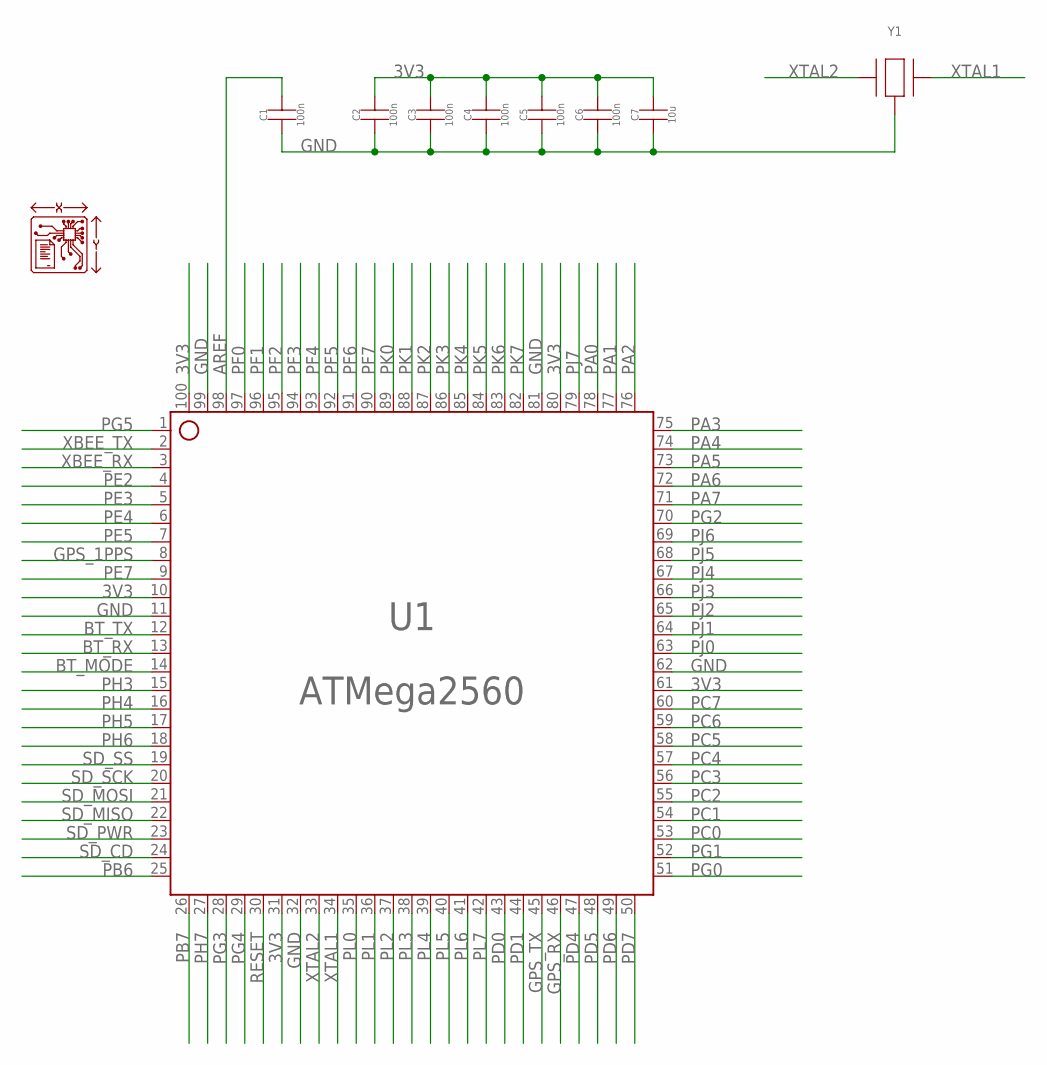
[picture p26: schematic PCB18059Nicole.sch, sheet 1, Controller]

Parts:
B1: PCB_TEMPLATE4X4IN; TEMPLATE_4X4IN
C1, C2, C3, C4, C5, C6: 100n; 0603
C7: 10u; 1206
U1: ATMega2560; 100QFP
Y1: XRES1206; 1206XRES

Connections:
3V3: C2.1, C3.1, C4.1, C5.1, C6.1, C7.1, U1.10, U1.31, U1.61, U1.80, U1.100; also elsewhere on the board
AREF: C1.1, U1.98
BT_MODE: U1.14; also elsewhere on the board
BT_RX: U1.13; also elsewhere on the board
BT_TX: U1.12; also elsewhere on the board
GND: C1.2, C2.2, C3.2, C4.2, C5.2, C6.2, C7.2, U1.11, U1.32, U1.62, U1.81, U1.99, Y1.2; also elsewhere on the board
GPS_1PPS: U1.8; also elsewhere on the board
GPS_RX: U1.46; also elsewhere on the board
GPS_TX: U1.45; also elsewhere on the board
PA0: U1.78
PA1: U1.77
PA2: U1.76
PA3: U1.75
PA4: U1.74
PA5: U1.73
PA6: U1.72
PA7: U1.71
PB6: U1.25
PB7: U1.26
PC0: U1.53
PC1: U1.54
PC2: U1.55
PC3: U1.56
PC4: U1.57
PC5: U1.58
PC6: U1.59
PC7: U1.60
PD0: U1.43
PD1: U1.44
PD4: U1.47
PD5: U1.48
PD6: U1.49
PD7: U1.50
PE2: U1.4
PE3: U1.5
PE4: U1.6
PE5: U1.7
PE7: U1.9
PF0: U1.97
PF1: U1.96
PF2: U1.95
PF3: U1.94
PF4: U1.93
PF5: U1.92
PF6: U1.91
PF7: U1.90
PG0: U1.51
PG1: U1.52
PG2: U1.70
PG3: U1.28
PG4: U1.29
PG5: U1.1
PH3: U1.15
PH4: U1.16
PH5: U1.17
PH6: U1.18
PH7: U1.27
PJ0: U1.63
PJ1: U1.64
PJ2: U1.65
PJ3: U1.66
PJ4: U1.67
PJ5: U1.68
PJ6: U1.69
PJ7: U1.79
PK0: U1.89
PK1: U1.88
PK2: U1.87
PK3: U1.86
PK4: U1.85
PK5: U1.84
PK6: U1.83
PK7: U1.82
PL0: U1.35
PL1: U1.36
PL2: U1.37
PL3: U1.38
PL4: U1.39
PL5: U1.40
PL6: U1.41
PL7: U1.42
RESET: U1.30
SD_CD: U1.24; also elsewhere on the board
SD_MISO: U1.22; also elsewhere on the board
SD_MOSI: U1.21; also elsewhere on the board
SD_PWR: U1.23; also elsewhere on the board
SD_SCK: U1.20; also elsewhere on the board
SD_SS: U1.19; also elsewhere on the board
XBEE_RX: U1.3; also elsewhere on the board
XBEE_TX: U1.2; also elsewhere on the board
XTAL1: U1.34, Y1.3
XTAL2: U1.33, Y1.1

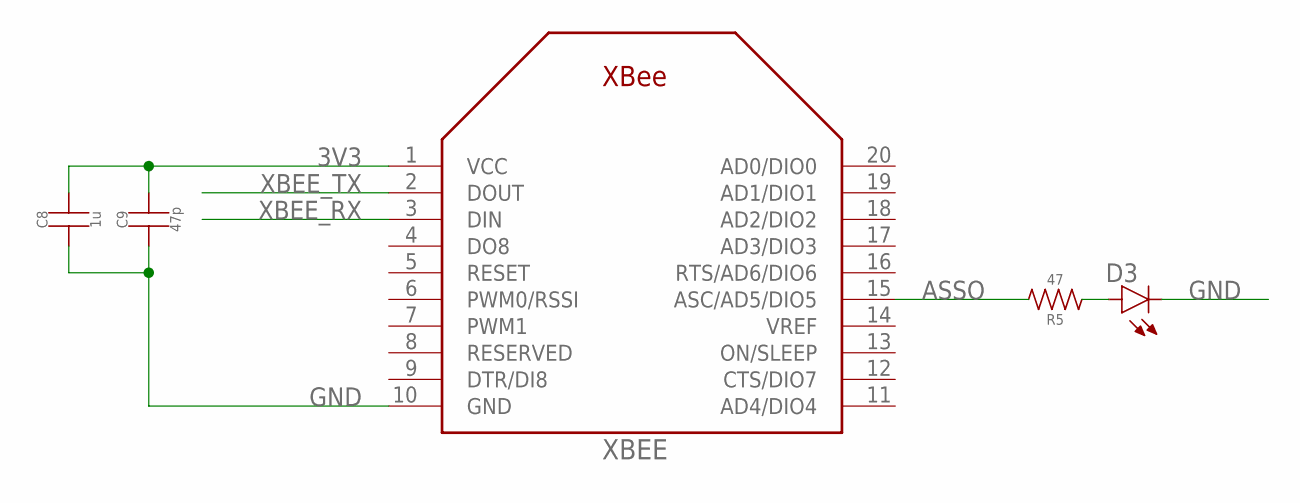
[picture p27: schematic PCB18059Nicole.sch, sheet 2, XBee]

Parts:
C8: 1u; 0603
C9: 47p; 0603
D3: LED0603; 0603
R5: 47; 0603
XBEE: XBEE

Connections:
3V3: C8.1, C9.1, XBEE.1 (VCC); also elsewhere on the board
ASSO: R5.1, XBEE.15 (ASC/AD5/DIO5)
GND: C8.2, C9.2, D3.2 (C), XBEE.10 (GND); also elsewhere on the board
unnamed: D3.1 (A), R5.2
XBEE_RX: XBEE.3 (DIN); also elsewhere on the board
XBEE_TX: XBEE.2 (DOUT); also elsewhere on the board

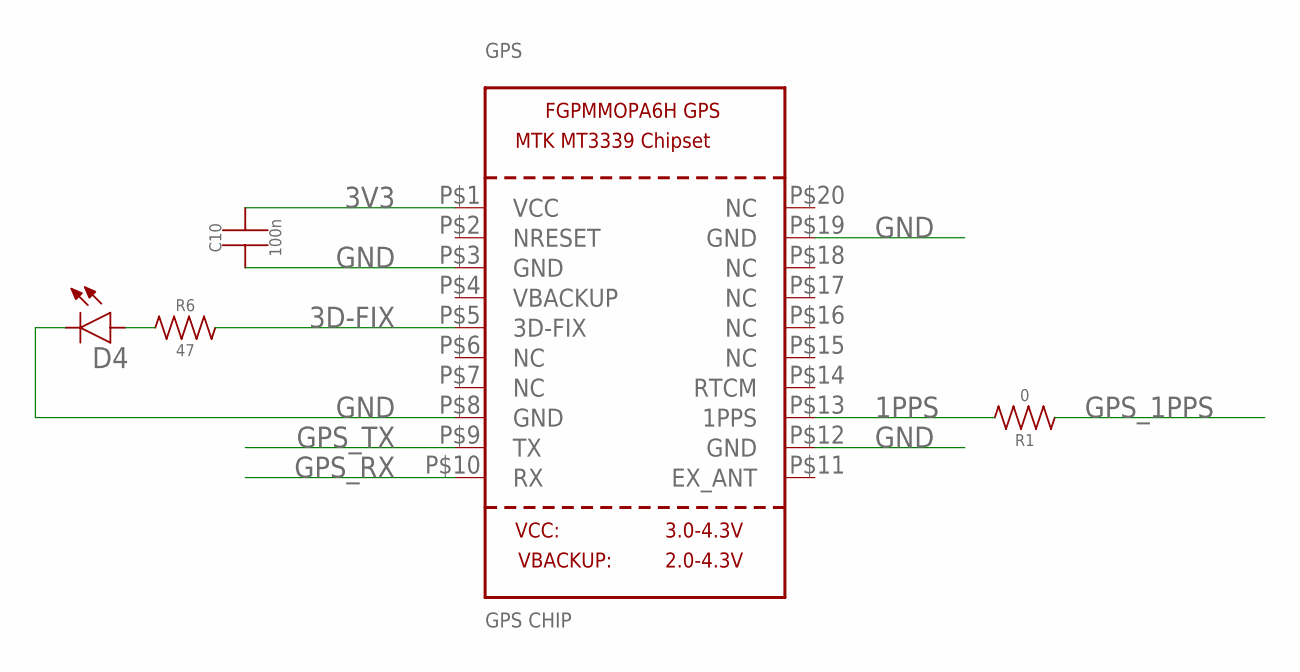
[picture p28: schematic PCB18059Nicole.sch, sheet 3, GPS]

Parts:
C10: 100n; 0603
D4: LED0603; 0603
GPS: GPS CHIP; FGPMMOPA6H
R1: 0; 0603
R6: 47; 0603

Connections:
1PPS: GPS.P$13 (1PPS), R1.1
3D-FIX: GPS.P$5 (3D-FIX), R6.1
3V3: C10.1, GPS.P$1 (VCC); also elsewhere on the board
GND: C10.2, D4.2 (C), GPS.P$3 (GND), GPS.P$8 (GND), GPS.P$12 (GND), GPS.P$19 (GND); also elsewhere on the board
GPS_1PPS: R1.2; also elsewhere on the board
GPS_RX: GPS.P$10 (RX); also elsewhere on the board
GPS_TX: GPS.P$9 (TX); also elsewhere on the board
unnamed: D4.1 (A), R6.2


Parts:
BT: ADAFRUIT_BLUETOOTH_LE_UART_FRIEND
DFU: PINHD-1X2""; 1X02

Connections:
3V3: BT.VIN; also elsewhere on the board
BT_MODE: BT.MOD; also elsewhere on the board
BT_RX: BT.RXI; also elsewhere on the board
BT_TX: BT.TXO; also elsewhere on the board
DFU: BT.DFU, DFU.1
GND: BT.CTS, BT.GND, DFU.2; also elsewhere on the board


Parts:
D1, D2: LED0603; 0603
Q1: FDC645N; SOT23-6
R2: 10k; 0603
R3, R4: 47; 0603
SD: MICROSDFRONT; USD,FRONT

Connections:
3V3: R3.1, R4.1, SD.4 (VCC); also elsewhere on the board
GND: Q1.4 (S), R2.2; also elsewhere on the board
unnamed: D1.1 (A), R3.2
unnamed: D2.1 (A), R4.2
SD_CD: SD.SW (CD); also elsewhere on the board
SD_GND: D1.2 (C), Q1.1 (D), Q1.2 (D), Q1.5 (D), Q1.6 (D), SD.1 (GND), SD.6 (GND), SD.8 (GND), SD.S0 (GND), SD.S1 (GND), SD.S2 (GND), SD.S3 (GND)
SD_MISO: SD.7 (DO); also elsewhere on the board
SD_MOSI: SD.3 (DI); also elsewhere on the board
SD_PWR: Q1.3 (G), R2.1; also elsewhere on the board
SD_SCK: D2.2 (C), SD.5 (SCK); also elsewhere on the board
SD_SS: SD.2 (CS); also elsewhere on the board


Board: 2 copper layers, 101.6 x 101.6 mm, 29 parts (0 on the bottom side), 28 nets.

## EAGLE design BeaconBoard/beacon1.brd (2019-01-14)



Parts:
3V3_ON_LED, 5V_ON_LED, 5V_ON_LED1: GREEN; LED-1206
3V3_REV_LED, 5V_REV_LED, 5V_REV_LED1: RED; LED-1206
ATMEGA2560: ATMEGA2560-16AU; TQFP100
BATT1, BATT2: Battery; 1X02_OVAL
C4, C5: CC1206; C1206
C6, C7, C9, C10: 100n; C1206K
C11: 22p; C1206K
C22, C23: 100m; C1206K
D4: CD1206-S01575; MINIMELF
FTDI1: PINHD-1X6CB; 1X06-CLEANBIG
IC7: LMV358IDGKR; MSOP08
ICSP: 3x2M; 2X03
JP1: HEADER-1X970MIL; 1X09_ROUND_70
JP3: PINHD-1X8BIG; 1X08-BIG
JP4, JP5: HEADER-1X770MIL; 1X07_ROUND_70
JP6: HEADER-1X876MIL; 1X08_ROUND_76
JP8: PWR_IN_0.1; 1X02_OVAL
JP10: LOAD_0.1; 1X02_OVAL
JP11: BATT_IN_0.1; 1X02_OVAL
L: YELLOW; LED-1206
LED2: LED1206; CHIPLED_1206
PWRIN_ON_LED: GREEN; LED-1206
PWRIN_REV_LED: RED; LED-1206
R1: 10; R0805
R4: 1K; 0805-NO
R5: 1M; R1206
R10: 1k; M1206
R11, R12, R13: 10k; M1206
R36, R37, R38, R39, R40, R41, R54: R-US_M1206; M1206
RESET: TS42031-160R-TR-7260; TS42
SOLAR: Solar; 1X02_OVAL
U1: M95M02-DWMN3TP/K; SOIC127P600X175-8N
U$1: XBEE
U$31: DC877A
USB_POWER_ON_LED: GREEN; LED-1206
Y1: CSTCE16M0V53-R0 16MHZ; RESONATOR

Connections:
1PPS: JP1.1
3.3V: C23.2, JP1.9, JP3.2, JP5.5, U1.8 (VCC)
3V3: 3V3_ON_LED.A, C4.1, C5.1, R36.1, U$1.1 (VCC)
5-GND: RESET.5 (5-GND)
5.0V: 5V_REV_LED1.A, FTDI1.3, JP1.2, JP3.1, JP4.7, JP5.7, JP6.4, JP8.2
5V: 5V_ON_LED.A, ATMEGA2560.10 (VCC), ATMEGA2560.31 (VCC1), ATMEGA2560.61 (VCC2), ATMEGA2560.80 (VCC3), ATMEGA2560.100 (AVCC), C7.1, C9.1, C10.1, D4.C, ICSP.2, R11.1, R12.1, R13.1, R37.1
90348: 3V3_REV_LED.A, 5V_REV_LED.A, ATMEGA2560.11 (GND), ATMEGA2560.32 (GND1), ATMEGA2560.62 (GND2), ATMEGA2560.81 (GND3), ATMEGA2560.99 (AGND), C6.2, C7.2, C9.2, C10.2, C11.2, L.C, PWRIN_REV_LED.A, R38.1, R39.1, R40.1, R41.1, RESET.1, RESET.2, U$31.2 (GND), Y1.2
+5V2: BATT1.2, BATT2.2, JP11.2
ADC0: ATMEGA2560.97 ((ADC0)PF0)
ADC1: ATMEGA2560.96 ((ADC1)PF1)
ADC2: ATMEGA2560.95 ((ADC2)PF2)
ADC3: ATMEGA2560.94 ((ADC3)PF3)
ADC4: ATMEGA2560.93 ((ADC4/TCK)PF4)
ADC5: ATMEGA2560.92 ((ADC5/TMS)PF5)
ADC6: ATMEGA2560.91 ((ADC6/TDO)PF6)
ADC7: ATMEGA2560.90 ((ADC7/TDI)PF7)
ADC8: ATMEGA2560.89 (PK0(ADC8/PCINT16))
ADC9: ATMEGA2560.88 (PK1(ADC9/PCINT17))
ADC10: ATMEGA2560.87 (PK2(ADC10/PCINT18))
ADC11: ATMEGA2560.86 (PK3(ADC11/PCINT19))
ADC12: ATMEGA2560.85 (PK4(ADC12/PCINT20))
ADC13: ATMEGA2560.84 (PK5(ADC13/PCINT21))
ADC14: ATMEGA2560.83 (PK6(ADC14/PCINT22))
ADC15: ATMEGA2560.82 (PK7(ADC15/PCINT23))
ADO: ATMEGA2560.79 (PJ7)
AREF: ATMEGA2560.98 (AREF), C6.1
CAN_CS: ATMEGA2560.37 (PL2(T5))
CAN_INT: ATMEGA2560.67 (PJ4(PCINT13))
CAN_RESET: ATMEGA2560.15 (PH3(OC4A))
CAN_RX0BF: ATMEGA2560.41 (PL6)
CAN_RX1BF: ATMEGA2560.42 (PL7)
CAN_TX0RTS: ATMEGA2560.38 (PL3(OC5A))
CAN_TX1RTS: ATMEGA2560.39 (PL4(OC5B))
CAN_TX2RTS: ATMEGA2560.40 (PL5(OC5C))
CD: JP3.8
DFU_5V: JP6.1
ENABLE: JP1.8
FIX: JP1.6
GND: C4.2, C5.2, FTDI1.1, ICSP.6, JP1.3, JP3.3, JP4.3, JP4.6, JP5.6, JP6.2, JP8.1, JP10.1, JP11.1, LED2.C, SOLAR.1, U1.4 (VSS), U$1.10 (GND)
GND2: BATT1.1
GND3: BATT2.1
IMU_CS_HI: ATMEGA2560.35 (PL0(ICP4))
IMU_INT_HI: ATMEGA2560.68 (PJ5(PCINT14))
L13: IC7.1 (OUT), IC7.2 (-IN), R10.2
LED0: ATMEGA2560.53 ((A8)PC0)
LED1: ATMEGA2560.54 ((A9)PC1)
LED2: ATMEGA2560.55 ((A10)PC2)
LED3: ATMEGA2560.56 ((A11)PC3)
LED4: ATMEGA2560.57 ((A12)PC4)
LED5: ATMEGA2560.58 ((A13)PC5)
LED6: ATMEGA2560.59 ((A14)PC6)
LED7: ATMEGA2560.60 ((A15)PC7)
LED8: ATMEGA2560.78 ((AD0)PA0)
LED9: ATMEGA2560.77 ((AD1)PA1)
LED10: ATMEGA2560.76 ((AD2)PA2)
LED11: ATMEGA2560.75 ((AD3)PA3)
LED12: ATMEGA2560.74 ((AD4)PA4)
LED13: ATMEGA2560.73 ((AD5)PA5)
LED14: ATMEGA2560.72 ((AD6)PA6)
LED15: ATMEGA2560.71 ((AD7)PA7)
MISO: ATMEGA2560.22 ((MISO/PCINT3)PB3), ICSP.1, JP3.5, U1.2 (Q)
MODE_5V: JP6.8
MOSI: ATMEGA2560.21 ((MOSI/PCINT2)PB2), ICSP.4, JP3.6, U1.5 (D)
unnamed: 5V_ON_LED1.A, JP10.2
unnamed: FTDI1.6, R1.1
unnamed: JP4.1, SOLAR.2
unnamed: LED2.A, R4.2
unnamed: L.A, R10.1
unnamed: PWRIN_ON_LED.C, R40.2
unnamed: R41.2, USB_POWER_ON_LED.C
unnamed: PWRIN_REV_LED.C, R54.2
unnamed: C23.1, U$31.3 (VOUT)
unnamed: C22.1, U$31.5 (VIN)
unnamed: 5V_ON_LED1.C, 5V_REV_LED1.C, C22.2
unnamed: 3V3_REV_LED.C, R36.2
unnamed: 5V_ON_LED.C, R38.2
unnamed: R4.1, U$1.15 (ASC/AD5/DIO5)
unnamed: 5V_REV_LED.C, R37.2
unnamed: 3V3_ON_LED.C, R39.2
PB0: ATMEGA2560.19 ((SS/PCINT0)PB0), JP3.7, U1.1 (!S)
PB4: ATMEGA2560.23 ((OC2A/PCINT4)PB4), JP6.3
PB5: ATMEGA2560.24 ((OC1A/PCINT5)PB5), JP6.7
PB6: ATMEGA2560.25 ((OC1B/PCINT6)PB6), FTDI1.2
PB7: ATMEGA2560.26 ((OC0A/OC1C/PCINT7)PB7), IC7.3 (+IN)
PD7: ATMEGA2560.50 ((T0)PD7)
PE3: ATMEGA2560.5 ((OC3A/AIN1)PE3)
PE4: ATMEGA2560.6 ((OC3B/INT4)PE4)
PE5: ATMEGA2560.7 ((OC3C/INT5)PE5)
PE6: ATMEGA2560.8 ((T3/INT6)PE6)
PE7: ATMEGA2560.9 ((CLKO/ICP3/INT7)PE7)
PG: JP4.5
PG0: ATMEGA2560.51 ((WR)PG0)
PG1: ATMEGA2560.52 ((RD)PG1)
PG2: ATMEGA2560.70 ((ALE)PG2)
PG5: ATMEGA2560.1 ((OC0B)PG5)
PH4: ATMEGA2560.16 (PH4(OC4B))
PH5: ATMEGA2560.17 (PH5(OC4C))
PH6: ATMEGA2560.18 (PH6(OC2B))
PS: JP4.4
PWRIN: PWRIN_ON_LED.A, R54.1
RESET: ATMEGA2560.30 (RESET), C11.1, D4.A, ICSP.5, R1.2, R11.2, RESET.3, RESET.4
RI: ATMEGA2560.66 (PJ3(PCINT12))
RXD0: FTDI1.4
RXD1: ATMEGA2560.45 ((RXD1/INT2)PD2)
RXD2: ATMEGA2560.12 (PH0(RXD2)), JP6.6
RXD3: ATMEGA2560.63 (PJ0(RXD3/PCINT9)), JP1.5
RX_1: U$1.2 (DOUT)
SCK: ATMEGA2560.20 ((SCK/PCINT1)PB1), ICSP.3, JP3.4, U1.6 (C)
SCL: ATMEGA2560.43 ((SCL/INT0)PD0), R13.2
SDA: ATMEGA2560.44 ((SDA/INT1)PD1), R12.2
SD_CARD_DETECT_1: ATMEGA2560.69 (PJ6(PCINT15))
SD_CS_HI: ATMEGA2560.36 (PL1(ICP5))
SLEEP: ATMEGA2560.65 (PJ2(XCK3/PCINT11))
TXD0: FTDI1.5
TXD1: ATMEGA2560.46 ((TXD1/INT3)PD3)
TXD2: ATMEGA2560.13 (PH1(TXD2)), JP6.5
TXD3: ATMEGA2560.64 (PJ1(TXD3/PCINT10)), JP1.4
TX_1: U$1.3 (DIN)
USBVCC: USB_POWER_ON_LED.A
V+: IC7.8 (V+)
V-: IC7.4 (V-)
VBACKUP: JP1.7
XBEE_SIGNAL_1: U$1.6 (PWM0/RSSI)
XTAL1: ATMEGA2560.34 (XTAL1), R5.1, Y1.3
XTAL2: ATMEGA2560.33 (XTAL2), R5.2, Y1.1

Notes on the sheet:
Arduino MEGA 2560
(SCK)
(MISO)
(MOSI)
pwm
Bluetooth chip and relevant power circuitry from schematic
Power circuitry dfrom Arduino reference schematic, may be changed from linear regulators to bucks for efficency
Reset
FTDI Chip for programming
Arduino Mega Reference
Xbee Reference
GPS circuit from Adafruit
Misc circuitry, including ICSP programing header, status leds, I2C pull ups
SD Card and EEPROM



Board: 2 copper layers, 101.6 x 100.0 mm, 55 parts (4 on the bottom side), 43 nets.

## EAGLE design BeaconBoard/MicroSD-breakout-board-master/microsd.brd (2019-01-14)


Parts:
ACT: RED; CHIP-LED0805
C1: 10uF/10V; A/3216-18R
C2: 0.1uF; C0805K
IC1: 4050D; SO16
IC2: LP298XS; SOT23-5L
JP1: PINHD-1X8BIG; 1X08-BIG
R1: 1K; R0805
U$1, U$2: FIDUCIAL; FIDUCIAL_1MM
X1: MICROSD

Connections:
+3V3: C1.+, IC1.1 (VDD), IC2.5 (VOUT), JP1.2, X1.4 (VDD)
CD: JP1.8, X1.CD1 (CARD_DETECT)
CLK: IC1.3 (I), IC1.9 (I), JP1.4
CS: IC1.7 (I), JP1.7
DI: IC1.5 (I), JP1.6
DO: JP1.5, X1.7 (DATA_OUT)
GND: C1.-, C2.2, IC1.8 (VSS), IC1.11 (I), IC1.14 (I), IC2.2 (GND), JP1.3, X1.6 (VSS), X1.MT1 (GND), X1.MT2 (GND1)
unnamed: ACT.A, IC1.10 (O)
unnamed: IC1.2 (O), X1.5 (SCLK)
unnamed: IC1.6 (O), R1.1, X1.2 (CS)
unnamed: ACT.C, R1.2
unnamed: IC1.4 (O), X1.3 (DATA_IN)
VCC: C2.1, IC2.1 (VIN), IC2.3 (EN), JP1.1


Board: 2 copper layers, 31.8 x 25.4 mm, 10 parts (0 on the bottom side), 13 nets.

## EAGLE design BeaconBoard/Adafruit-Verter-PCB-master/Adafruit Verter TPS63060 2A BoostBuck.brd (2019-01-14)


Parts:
C1, C2: 10uF/16V X5R; 0805-NO
C3: 0.1uF; 0805-NO
C4: 10pF; 0805-NO
C5, C6, C7: 22uF/10V X5R; 0805-NO
C8: 1uF/10V X5R; 0805-NO
CN1: USBA_FEMALE; USB_HOST-PTH
D1: GREEN; CHIPLED_0805_NOOUTLINE
FID1, FID2: FIDUCIAL""; FIDUCIAL_1MM
JP1: HEADER-1X770MIL; 1X07_ROUND_70
L1: NRS5030T1R0NMGJ; INDUCTOR_5X5MM_TDK_VLC5045
Q1: BSS138; SOT23-WIDE
R1, R3: 1M; 0805-NO
R2, R5, R6: 105K; 0805-NO
R4: 1K; 0805-NO
R9, R11: 75K 1%; 0805-NO
R10, R12: 49.9K 1%; 0805-NO
U1: TPS63060; PWSON-N10
U$15, U$17: MOUNTINGHOLE2.5; MOUNTINGHOLE_2.5_PLATED
X1, X2: TERMBLOCK_1X2; TERMBLOCK_1X2-3.5MM

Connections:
5.0V: C5.1, C6.1, C7.1, C8.1, CN1.VBUS, D1.A, JP1.7, R1.2, R3.2, R9.2, R11.2, U1.9 (VOUT), X2.2
D+: CN1.D+, R11.1, R12.1
D-: CN1.D-, R9.1, R10.1
ENABLE: JP1.2, R5.2, U1.3 (EN)
GND: C1.2, C2.2, C3.2, C4.2, C5.2, C6.2, C7.2, C8.2, CN1.GND, JP1.3, JP1.6, Q1.2 (S), R2.1, R6.2, R10.2, R12.2, U1.7 (GND), U1.THERMAL@1 (PGND), U1.THERMAL@5 (PGND), U1.THERMAL@6 (PGND), U1.THERMAL@7 (PGND), U1.THERMAL@8 (PGND), U1.THERMAL@9 (PGND), U1.THERMAL@10 (PGND), U1.THERMAL@11 (PGND), U1.THERMAL@12 (PGND), U1.THERMAL@13 (PGND), U1.THERMAL@14 (PGND), X1.1, X2.1
unnamed: L1.P$1 (1), U1.1 (L1)
unnamed: L1.P$2 (2), U1.10 (L2)
unnamed: C3.1, U1.6 (VAUX)
unnamed: D1.C, R4.1
unnamed: C4.1, R1.1, R2.2, U1.8 (FB)
unnamed: Q1.3 (D), R4.2
PG: JP1.5, Q1.1 (G), R3.1, U1.5 (PG)
PS: JP1.4, R6.1, U1.4 (PSYNC)
VIN: C1.1, C2.1, JP1.1, R5.1, U1.2 (VIN), X1.2


Board: 2 copper layers, 31.8 x 19.1 mm, 37 parts (1 on the bottom side), 14 nets.

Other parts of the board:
U$22, U$23: SYMBOL_PLUS
U$24, U$25: SYMBOL_MINUS
U$27: ADAFRUIT_3.5MM
U$37: VERTERLOGO
U$38: PCBFEAT-REV-040

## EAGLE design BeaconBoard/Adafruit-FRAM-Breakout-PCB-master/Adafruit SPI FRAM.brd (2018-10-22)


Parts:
C1: 10uF; _0805MP
FID1, FID2: FIDUCIAL""; FIDUCIAL_1MM
JP1: HEADER-1X870MIL; 1X08_ROUND_70
R2: 10K; _0805MP
U1: MB85RS64VPNF-G-JNERE1; SOIC8_150MIL
U$5, U$6: MOUNTINGHOLE2.5; MOUNTINGHOLE_2.5_PLATED

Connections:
CS: JP1.2, U1.1 (CS)
GND: C1.2, JP1.7, U1.4 (GND)
HOLD: JP1.6, R2.1, U1.7 (HOLD)
MISO: JP1.4, U1.2 (MISO)
MOSI: JP1.3, U1.5 (MOSI)
SCK: JP1.5, U1.6 (SCK)
VCC: C1.1, JP1.8, R2.2, U1.8 (VCC)
WP: JP1.1, U1.3 (WP)


Board: 2 copper layers, 20.3 x 15.2 mm, 10 parts (1 on the bottom side), 8 nets.

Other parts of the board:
U$4, U$7: ADAFRUIT_3.5MM

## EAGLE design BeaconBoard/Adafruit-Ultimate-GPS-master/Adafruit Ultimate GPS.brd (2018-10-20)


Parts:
B1: CR1220
C1: 0.1uF; 0805-NO
C2, C3: 10uF; 0805-NO
D1: 1N4148; SOD-323
D2: CUS520; SOD-323
FB1: Ferrite; 0805-NO
FID1, FID2: FIDUCIAL""; FIDUCIAL_1MM
JP1: HEADER-1X970MIL; 1X09_ROUND_70
LED1: RED; CHIPLED_0805
R1: 1K; 0805-NO
R2, R3: 10K; 0805-NO
U1: FGPMMOPA6H
U2: MIC5225-3.3; SOT23-5
U$8, U$9: MOUNTINGHOLE2.5; MOUNTINGHOLE_2.5_PLATED
U$20: U.FL

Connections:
1PPS: JP1.1, U1.P$13 (1PPS)
3.3V: C1.1, C2.1, FB1.2, JP1.9, R3.1, U1.P$1 (VCC)
ENABLE: JP1.8, R2.1, U2.3 (EN)
FIX: JP1.6, LED1.A, U1.P$5 (3D-FIX)
GND: B1.-, C1.2, C2.2, C3.2, JP1.3, R1.1, U1.P$3 (GND), U1.P$8 (GND), U1.P$12 (GND), U1.P$19 (GND), U2.2 (GND), U$20.P$1 (GND), U$20.P$2 (GND)
unnamed: B1.+$1 (+), B1.+$2 (+), D2.A
unnamed: LED1.C, R1.2
unnamed: FB1.1, U2.5 (OUT)
unnamed: U1.P$11 (EX_ANT), U$20.P$3 (SIGNAL)
RX: D1.C, JP1.4
RX_3V: D1.A, R3.2, U1.P$10 (RX)
TX: JP1.5, U1.P$9 (TX)
VBACKUP: D2.C, JP1.7, U1.P$4 (VBACKUP)
VIN: C3.1, JP1.2, R2.2, U2.1 (IN)

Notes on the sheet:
D1+R3 restrict RX input to 3.3V



Board: 2 copper layers, 25.4 x 34.3 mm, 22 parts (3 on the bottom side), 14 nets.

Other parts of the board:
U$15: ADAFRUIT_2.5MM
U$16: PCBFEAT-REV-040
U$18: ADAFRUIT_5MM

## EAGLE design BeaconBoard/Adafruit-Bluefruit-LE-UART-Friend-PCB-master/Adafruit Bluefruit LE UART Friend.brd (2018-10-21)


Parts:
C1, C2: 1uF; 0805-NO
C3, C4: 10uF; 0805-NO
D1: RED; CHIPLED_0805_NOOUTLINE
D2: GREEN; CHIPLED_0805_NOOUTLINE
D3, D8: MBR120; SOD-123
D4, D5, D6, D7: 1n4148; SOD-323
FID1, FID2: FIDUCIAL""; FIDUCIAL_1MM
JP1: HEADER-1X876MIL; 1X08_ROUND_76
R1, R2: 1K; 0805-NO
R3, R4: 100K; 0805-NO
R7: 2K; 0805-NO
SW1: EG1319; EG1390
TP1: SWCLK; PAD-1.5X2.0
TP2: SWDIO; PAD-1.5X2.0
TP3: FCTRST; PAD-1.5X2.0
U1: NRF51822_MODULE_MDBT40; BLE_MODULE_RAYTAC_MDBT40
U2: MIC5225-3.3; SOT23-5
U$28, U$29: MOUNTINGHOLE2.5; MOUNTINGHOLE_2.5_PLATED
VTREF: FCTRST; PAD-1.5X2.0
X1: JST 2PH; JSTPH2
Y1: 32.768kHz (535-9166-2-ND); CRYSTAL_CYL_2X6MM_SMT

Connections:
3.3V: C1.1, C2.1, C4.1, R3.2, R4.2, SW1.O2, U1.3 (AVDD), U1.14 (VDD), U2.5 (OUT), VTREF.P$1
CONNECTED_LED: R2.1, U1.39 (P0.19)
CTS_3V: D4.A, R3.1, U1.28 (P0.10)
CTS_5V: D4.C, JP1.7
DCC: U1.15 (DCC)
DEC2: U1.41 (DEC2)
DFU_3V: D7.A, U1.24 (P0.07)
DFU_5V: D7.C, JP1.1
FCTRYRST_3V: TP3.P$1, U1.34 (P0.16)
GND: C1.2, C2.2, C3.2, C4.2, D1.C, D2.C, JP1.2, SW1.S2, U1.1 (GND), U1.2 (GND), U1.13 (GND), U1.16 (P0.30), U1.25 (GND), U1.42 (GND), U2.2 (GND), X1.1
MODE_3V: D6.A, U1.18 (P0.01/AIN2)
MODE_5V: D6.C, JP1.8, R7.1
MODE_LED: R1.1, U1.38 (P0.18)
unnamed: U1.9 (P0.26/AIN0/XL2), Y1.1
unnamed: U1.10 (P0.27/AIN1/XL1), Y1.2
unnamed: C3.1, D3.C, D8.C, U2.1 (IN), U2.3 (EN)
unnamed: R7.2, SW1.P2
unnamed: D1.A, R1.2
unnamed: D2.A, R2.2
RTS_O: JP1.3, U1.26 (P0.08)
RXD_3V: D5.A, R4.1, U1.29 (P0.11)
RXD_5V: D5.C, JP1.5
SWCLK: TP1.P$1, U1.36 (SWCLK)
SWDIO/RST_3V: TP2.P$1, U1.35 (SWDIO/NRESET)
TX_O: JP1.6, U1.27 (P0.09)
VBAT: D3.A, X1.2
VIN: D8.A, JP1.4

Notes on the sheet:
DATA
CMD
To control MODE in SW (using the MODE_5V pin) set SW1 high (to CMD), which allows MODE_5V to change mode by setting it directly to GND or VIN



Board: 2 copper layers, 21.3 x 31.8 mm, 35 parts (9 on the bottom side), 25 nets.

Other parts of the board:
U$9: BLUEFRUITLOGO_100MM
U$24: PCBFEAT-REV-040
U$25: ADAFRUIT_3.5MM
U$26: ADAFRUIT_2.5MM

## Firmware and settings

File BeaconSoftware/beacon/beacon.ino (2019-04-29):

/*********************************************************************
  This is an example for our nRF51822 based Bluefruit LE modules

  Pick one up today in the adafruit shop!

  Adafruit invests time and resources providing this open source code,
  please support Adafruit and open-source hardware by purchasing
  products from Adafruit!

  MIT license, check LICENSE for more information
  All text above, and the splash screen below must be included in
  any redistribution
*********************************************************************/

#include <Arduino.h>
#include <SPI.h>
#include "Adafruit_BLE.h"
#include "Adafruit_BluefruitLE_SPI.h"
#include "Adafruit_BluefruitLE_UART.h"
#include <Adafruit_GPS.h>

#include "BluefruitConfig.h"

#if SOFTWARE_SERIAL_AVAILABLE
#include <SoftwareSerial.h>
#endif

/*=========================================================================
    APPLICATION SETTINGS

      FACTORYRESET_ENABLE     Perform a factory reset when running this sketch
     
                              Enabling this will put your Bluefruit LE module
                            in a 'known good' state and clear any config
                            data set in previous sketches or projects, so
                              running this at least once is a good idea.
     
                              When deploying your project, however, you will
                            want to disable factory reset by setting this
                            value to 0.  If you are making changes to your
                              Bluefruit LE device via AT commands, and those
                            changes aren't persisting across resets, this
                            is the reason why.  Factory reset will erase
                            the non-volatile memory where config data is
                            stored, setting it back to factory default
                            values.
         
                              Some sketches that require you to bond to a
                            central device (HID mouse, keyboard, etc.)
                            won't work at all with this feature enabled
                            since the factory reset will clear all of the
                            bonding data stored on the chip, meaning the
                            central device won't be able to reconnect.

    BEACON_MANUFACTURER_ID  Company Identifier assigned by Bluetooth SIG
                            Full list of Manufacturer ID can be found here
                            https://www.bluetooth.org/en-us/specification/assigned-numbers/company-identifiers
    BEACON_UUID             16-bytes UUID in hex format AA-BB-...
    BEACON_MAJOR            16-bit major nunber
    BEACON_MINOR            16-bit minor nunber
    BEACON_RSSI_1M
    -----------------------------------------------------------------------*/
#define FACTORYRESET_ENABLE      0

#define MANUFACTURER_APPLE         "0x004C"
#define MANUFACTURER_NORDIC        "0x0059"

#define BEACON_MANUFACTURER_ID     MANUFACTURER_APPLE
#define BEACON_UUID                "01-12-23-34-45-56-67-78-89-9A-AB-BC-CD-DE-EF-F0"
#define BEACON_MAJOR               "0x0000"
#define BEACON_MINOR               "0x0000"
#define BEACON_RSSI_1M             "-54"
#define MINIMUM_FIRMWARE_VERSION    "0.6.6"
#define MODE_LED_BEHAVIOUR          "MODE"
#define beaconid                    1
/*=========================================================================*/

// Create the bluefruit object, either software serial...uncomment these lines
/*
  SoftwareSerial bluefruitSS = SoftwareSerial(BLUEFRUIT_SWUART_TXD_PIN, BLUEFRUIT_SWUART_RXD_PIN);

  Adafruit_BluefruitLE_UART ble(bluefruitSS, BLUEFRUIT_UART_MODE_PIN,
                      BLUEFRUIT_UART_CTS_PIN, BLUEFRUIT_UART_RTS_PIN);
*/

/* ...or hardware serial, which does not need the RTS/CTS pins. Uncomment this line */
Adafruit_BluefruitLE_UART ble(BLUEFRUIT_HWSERIAL_NAME, BLUEFRUIT_UART_MODE_PIN);

/* ...hardware SPI, using SCK/MOSI/MISO hardware SPI pins and then user selected CS/IRQ/RST */
//Adafruit_BluefruitLE_SPI ble(BLUEFRUIT_SPI_CS, BLUEFRUIT_SPI_IRQ, BLUEFRUIT_SPI_RST);

/* ...software SPI, using SCK/MOSI/MISO user-defined SPI pins and then user selected CS/IRQ/RST */
//Adafruit_BluefruitLE_SPI ble(BLUEFRUIT_SPI_SCK, BLUEFRUIT_SPI_MISO,
//                             BLUEFRUIT_SPI_MOSI, BLUEFRUIT_SPI_CS,
//                             BLUEFRUIT_SPI_IRQ, BLUEFRUIT_SPI_RST);


// A small helper
void error(const __FlashStringHelper*err) {
  while (1) {
    Serial.println(err);
    delay(5000);
  }
}

#define GPSSerial Serial1
#define XBEESerial Serial3
Adafruit_GPS GPS(&GPSSerial);
#define GPSECHO false
double beaconLat;
double beaconLong;
int beaconTime[7] = {99, 99, 99, 99, 99, 99, 99};
;

uint32_t timer = millis();

/**************************************************************************/
/*!
    @brief  Sets up the HW an the BLE module (this function is called
            automatically on startup)
*/
/**************************************************************************/
void setup(void)
{
  while (!Serial);  // required for Flora & Micro
  delay(500);       // This may not be necessary, but it doesn't seem to be hurting anything

  XBEESerial.begin(38400);  // Baud rate from Nicole - shouldn't matter, but for consistency...
  Serial.begin(115200);     // Higher baud rate to reduce impact on performance due to debugging

  Serial.println("Adafruit GPS library basic test!");

  // 9600 NMEA is the default baud rate for Adafruit MTK GPS's- some use 4800
  GPS.begin(9600);
  // uncomment this line to turn on RMC (recommended minimum) and GGA (fix data) including altitude
  GPS.sendCommand(PMTK_SET_NMEA_OUTPUT_RMCGGA);
  // uncomment this line to turn on only the "minimum recommended" data
  //GPS.sendCommand(PMTK_SET_NMEA_OUTPUT_RMCONLY);
  // For parsing data, we don't suggest using anything but either RMC only or RMC+GGA since
  // the parser doesn't care about other sentences at this time
  // Set the update rate
  GPS.sendCommand(PMTK_SET_NMEA_UPDATE_1HZ); // 1 Hz update rate
  // For the parsing code to work nicely and have time to sort thru the data, and
  // print it out we don't suggest using anything higher than 1 Hz

  // Request updates on antenna status, comment out to keep quiet
  GPS.sendCommand(PGCMD_ANTENNA);

  beaconLat = 9999.99;
  beaconLong = 9999.99;
  delay(1000); // Delay is copied from GPS example code, may not be necessary

  // Ask for firmware version
  GPSSerial.println(PMTK_Q_RELEASE);

  Serial.println(F("Adafruit Bluefruit Beacon Example"));
  Serial.println(F("---------------------------------"));

  /* Initialise the module */
  Serial.print(F("Initialising the Bluefruit LE module: "));

  if ( !ble.begin(VERBOSE_MODE) )
  {
    error(F("Couldn't find Bluefruit, make sure it's in CoMmanD mode & check wiring?"));
  }
  Serial.println( F("OK!") );

  if ( FACTORYRESET_ENABLE )
  {
    /* Perform a factory reset to make sure everything is in a known state */
    Serial.println(F("Performing a factory reset: "));
    if ( ! ble.factoryReset() ) {
      error(F("Couldn't factory reset"));
    }
  }

  /* Disable command echo from Bluefruit */
  ble.echo(false);

  Serial.println("Requesting Bluefruit info:");
  /* Print Bluefruit information */
  ble.info();

  Serial.println(F("Setting beacon configuration details: "));

  // AT+BLEBEACON=0x004C,01-12-23-34-45-56-67-78-89-9A-AB-BC-CD-DE-EF-F0,0x0000,0x0000,-54
  ble.print("AT+BLEBEACON="        );
  ble.print(BEACON_MANUFACTURER_ID ); ble.print(',');
  ble.print(BEACON_UUID            ); ble.print(',');
  ble.print(BEACON_MAJOR           ); ble.print(',');
  ble.print(BEACON_MINOR           ); ble.print(',');
  ble.print(BEACON_RSSI_1M         );
  ble.println(); // print line causes the command to execute

  // check response status
  while (! ble.waitForOK() ) { // Hang until bluetooth is connected
    Serial.println(F("Bluetooth is not available, retry in 5 seconds"));
    delay(5000);
  }


  Serial.println();
  Serial.println(F("Open your beacon app to test"));

  //Serial.println(F("Please use Adafruit Bluefruit LE app to connect in UART mode"));
  //Serial.println(F("Then Enter characters to send to Bluefruit"));
  Serial.println();

  ble.verbose(false);  // debug info is a little annoying after this point!

  /* Wait for connection */
  // DEBUG: This is only here for testing, and will be removed before deployment
  while (! ble.isConnected()) {
    delay(500);
  }

  // LED Activity command is only supported from 0.6.6
  if ( ble.isVersionAtLeast(MINIMUM_FIRMWARE_VERSION) )
  {
    // Change Mode LED Activity
    Serial.println(F("******************************"));
    Serial.println(F("Change LED activity to " MODE_LED_BEHAVIOUR));
    ble.sendCommandCheckOK("AT+HWModeLED=" MODE_LED_BEHAVIOUR);
    Serial.println(F("******************************"));
  }
}

/**************************************************************************/
/*!
    @brief  Constantly poll for new command or response data
*/
/**************************************************************************/
void loop(void)
{
  //TODO: Move these to the setup / make them global

  // read data from the GPS in the 'main loop'
  while (GPSSerial.available()) {
    char c = GPS.read();
    // if you want to debug, this is a good time to do it!
    if (GPSECHO)
      if (c) Serial.print(c);
  }
  // if a sentence is received, we can check the checksum, parse it...
  if (GPS.newNMEAreceived()) {
    // a tricky thing here is if we print the NMEA sentence, or data
    // we end up not listening and catching other sentences!
    // so be very wary if using OUTPUT_ALLDATA and trytng to print out data
    //Serial.println(GPS.lastNMEA()); // this also sets the newNMEAreceived() flag to false
    if (!GPS.parse(GPS.lastNMEA())) { // this also sets the newNMEAreceived() flag to false
      //Serial.println("Couldn't parse most recent NMEA string");
      //return; // we can fail to parse a sentence in which case we should just wait for another
    }
  }
  // if millis() or timer wraps around, we'll just reset it
  if (timer > millis()) {
    timer = millis();
  }

  // approximately every 2 seconds or so, print out the current stats
  if (millis() - timer > 2000) {
    timer = millis(); // reset the timer
    Serial.print("\nTime: ");
    Serial.print(GPS.hour, DEC); Serial.print(':');
    Serial.print(GPS.minute, DEC); Serial.print(':');
    Serial.print(GPS.seconds, DEC); Serial.print('.');
    Serial.println(GPS.milliseconds);
    Serial.print("Date: ");
    Serial.print(GPS.day, DEC); Serial.print('/');
    Serial.print(GPS.month, DEC); Serial.print("/20");
    Serial.println(GPS.year, DEC);
    Serial.print("Fix: "); Serial.print((int)GPS.fix);
    Serial.print(" quality: "); Serial.println((int)GPS.fixquality);
    if (GPS.fix) {
      Serial.print("Location: ");
      Serial.print(GPS.latitude, 4); Serial.print(GPS.lat);
      Serial.print(", ");
      Serial.print(GPS.longitude, 4); Serial.println(GPS.lon);
      Serial.print("Speed (knots): "); Serial.println(GPS.speed);
      Serial.print("Angle: "); Serial.println(GPS.angle);
      Serial.print("Altitude: "); Serial.println(GPS.altitude);
      Serial.print("Satellites: "); Serial.println((int)GPS.satellites);
      beaconLat = GPS.latitude;
      beaconLong = GPS.longitude;
      beaconTime[0] = GPS.hour;
      beaconTime[1] = GPS.minute;
      beaconTime[2] = GPS.seconds;
      beaconTime[3] = GPS.milliseconds;
      beaconTime[4] = GPS.month;
      beaconTime[5] = GPS.day;
      beaconTime[6] = GPS.year;
    }
  }
  ble.println("AT+BLEUARTRX");
  ble.readline(); // Copy the BLE serial buffer into the BLE response buffer
  if (strcmp(ble.buffer, "OK") == 0) {  // Check the contents of the BLE response buffer
    // no data
  }
  else {
    // Some data was found, its in the buffer
    Serial.print(F("[Recv] ")); Serial.println(ble.buffer);
    Serial.print("[Send] ");
    Serial.println(ble.buffer);
    ble.print("AT+BLEUARTTX=");
    ble.println(ble.buffer);
    bool bleFlag = false;
    //int bbuffSize = sizeof(ble.buffer)/sizeof(ble.buffer[0]);
    unsigned int bbuffSize = ((String)ble.buffer).length();
    Serial.println(bbuffSize);
    String messageAlert;
    if (ble.buffer[0] == '#' && ble.buffer[bbuffSize - 1] == '~') {
      bleFlag = true; // There is a valid message
    }
    else {
      bleFlag = false; // There is not a valid message
    }
    if (bleFlag) {
      //Serial.print(ble.buffer[1]);
      //Serial.println(ble.buffer[2]);
      if (ble.buffer[1] == 'A' && ble.buffer[2] == 'T') {
        if(ble.buffer[4] == 'I' && ble.buffer[5] == 'D'){
          messageAlert = ((String)ble.buffer).substring(0, bbuffSize - 1);
          }
          else if(ble.buffer[4] == 'L' && ble.buffer[5] == 'N'){
            messageAlert += (String)ble.buffer).substring(4, bbuffSize - 5) + ",BI," + (String)beaconid + "~";
            
          }
          else{
            messageAlert += (String)ble.buffer).substring(4, bbuffSize - 5);
          }
        Serial.print("[Send] ");
        Serial.println(messageAlert);
        XBEESerial.println(messageAlert);

        //TODO: pass to main station
      }
      else if (ble.buffer[1] == 'G' & ble.buffer[2] == 'P') {
        String messageGPS = "#GP,LT," + (String)beaconLat + ",LN," + (String)beaconLong + "~";
        Serial.println(messageGPS);
        ble.print("AT+BLEUARTTX=");
        ble.println(messageGPS);
      }
      else {
        Serial.print("Unknown Command Received");
      }
    }
  }
  //ble.waitForOK();
  String xBeeBuff = "";
  unsigned int xbuffSize;
  while (XBEESerial.available()) {
    Serial.println("inside while loop");
    xBeeBuff  = XBEESerial.readString();
    xbuffSize = ((String)xBeeBuff).length();
    Serial.println(xBeeBuff);
    Serial.println((String)xbuffSize);
  }
  bool xBeeFlag = false;
  if (xBeeBuff[0] == '#' && xBeeBuff[xbuffSize - 1] == '~') {
    xBeeFlag = true;
  }
  else {
    xBeeFlag = false;
  }

  if (xBeeFlag) {
    if (xBeeBuff[1] == 'A' && xBeeBuff[2] == 'T') {
      String messageMainAck = xBeeBuff.substring(0, xbuffSize);
      ble.print("AT+BLEUARTTX=");
      ble.println(messageMainAck);
    }
    else if (xBeeBuff[1] == 'P' && xBeeBuff[2] == 'G' && xbuffSize == 4) {
      String messageBeaconAck = "#PG,ID," + (String)beaconid + ",LT," + (String)beaconLat + ",LN," + (String)beaconLong + ",TH," + beaconTime[0] + ",TM," + beaconTime[1] + ",TS," + beaconTime[2] + ",TF," + beaconTime[3] + ",TO," + beaconTime[4] + ",TD," + beaconTime[5] + ",TY," + beaconTime[6] + "~";

      Serial.println(messageBeaconAck);
      XBEESerial.println(messageBeaconAck);
    }
    else {
      Serial.println("invalid Xbee message");
    }
  }
}

/**************************************************************************/
/*!
    @brief  Checks for user input (via the Serial Monitor)
*/
/**************************************************************************/
bool getUserInput(char buffer[], uint8_t maxSize)
{
  // timeout in 100 milliseconds
  TimeoutTimer timeout(100);

  memset(buffer, 0, maxSize);
  while ( (!Serial.available()) && !timeout.expired() ) {
    delay(1);
  }

  if ( timeout.expired() ) return false;

  delay(2);
  uint8_t count = 0;
  do
  {
    count += Serial.readBytes(buffer + count, maxSize);
    delay(2);
  } while ( (count < maxSize) && (Serial.available()) );

  return true;
}

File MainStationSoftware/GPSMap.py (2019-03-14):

import os
import wx
import sys
import numpy as np
from numpy import interp
import csv
import beacon

import time

class Map(wx.Panel):
    def __init__(self, parent,beacons=[]):
        wx.Panel.__init__(self, parent)
        self.frame = parent
        self.beacons = beacons
        self.PhotoMaxSize = 1178
        self.photoTxt = 'map.png'

    def initMap(self, height=None):
        if height == None:
            self.height,self.width = self.frame.GetSize()
            self.PhotoMaxSize = min(self.frame.GetSize())
        else:
            self.PhotoMaxSize = height

        self.Bind(wx.EVT_KEY_DOWN, self.onKey)
        #self.createBeacons()
        self.setMapPoints("map.txt")
        self.createWidgets(self)
        self.onView(self)
        self.frame.Show()
    def refresh(self):
        self.onView(self)
        self.frame.Show()

    def displayBeacons(self):
        tmpx = (self.x1 + self.x2)/2
        tmpy = (self.y2 + self.y1)/2
        print(tmpx)
        for beacon in self.beacons:
            print(beacon.id)
            self.drawPosition(beacon.id, beacon.lat, beacon.lon, beacon.heading)
    def setMapPoints(self, coords):
        with open(coords) as f:
            lines = list(csv.reader(f, delimiter=","))
        self.y1 = float(lines[0][2])
        self.y2 = float(lines[0][0])
        self.x1 = float(lines[0][1])
        self.x2 = float(lines[0][3])

    def createWidgets(self, panel):
        img = wx.Image(1178,1056)
        self.imageCtrl = wx.StaticBitmap(panel, wx.ID_ANY,
                                         wx.Bitmap(img))

        self.mainSizer = wx.BoxSizer(wx.VERTICAL)
        self.sizer = wx.BoxSizer(wx.HORIZONTAL)

        self.mainSizer.Add(self.imageCtrl, 0, wx.ALL, 5)
        self.mainSizer.Add(self.sizer, 0, wx.ALL, 5)

        self.SetSizer(self.mainSizer)
        self.mainSizer.Fit(self.frame)

        self.Layout()

    def onKey(self, event):
        """
        Check for ESC key press and exit if ESC is pressed
        """
        key_code = event.GetKeyCode()
        if key_code == wx.WXK_ESCAPE:
            sys.exit(0)
        else:
            event.Skip()

    def onView(self, panel):
        filepath = self.photoTxt
        img = wx.Image(filepath, wx.BITMAP_TYPE_ANY)
        # scale the image, preserving the aspect ratio
        W = img.GetWidth()
        H = img.GetHeight()
        if W > H:
            NewW = self.PhotoMaxSize
            NewH = self.PhotoMaxSize * H / W
        else:
            NewH = self.PhotoMaxSize
            NewW = self.PhotoMaxSize * W / H
        img = img.Scale(NewW,NewH)

        self.bitmap = wx.Bitmap(img)
        #print(type(self.x1+self.x2))
        #print(type(self.x1))


        self.displayBeacons();
        self.imageCtrl.SetBitmap(self.bitmap)
        panel.Refresh()

    def drawPosition(self, beaconNum, lat, lon,angle):
        #print(lat,":",self.y1,self.y2,":","0",self.bitmap.GetHeight())
        #print(lon,":",self.x1,self.x2,":","0",self.bitmap.GetWidth())
        tmpimg = wx.Image("favicon.ico", wx.BITMAP_TYPE_ANY)

        img_centre = wx.Point( tmpimg.GetWidth()/2, tmpimg.GetHeight()/2 )
        tmpimg = tmpimg.Rotate( angle, img_centre )

        y = interp(lat,[self.y2,self.y1],[self.bitmap.GetHeight(),0])
        x = interp(lon,[self.x1,self.x2],[0,self.bitmap.GetWidth()])
        tmpimg = wx.Bitmap(tmpimg)

        #print(x,y)
        #print(self.bitmap.GetWidth(), self.bitmap.GetHeight())

        dc = wx.MemoryDC(self.bitmap)

        y -= tmpimg.GetHeight()/2
        x -= tmpimg.GetWidth()/2
        dc.DrawBitmap(tmpimg, x, y)
        # pen=wx.Pen('blue',4)
        # dc.SetPen(pen)
        # dc.DrawCircle(x+ tmpimg.GetWidth()/2,y+tmpimg.GetHeight()/2,2)
        # pen=wx.Pen('red',4)
        # dc.SetPen(pen)
        # dc.DrawCircle(x,y,2)
        dc.SelectObject(wx.NullBitmap)

def createBeacons():
    beacon1 = beacon.Beacon()
    beacon2 = beacon.Beacon()
    beacon3 = beacon.Beacon()
    beacon1.setGps(0,32.950327, -112.605402,0)
    beacon2.setGps(1,32.932162, -112.551885,45)
    beacon3.setGps(2,32.926696, -112.560383,90)
    return [beacon1,beacon2,beacon3]

if __name__ == '__main__':
    # app = PhotoCtrl()
    # app.MainLoop()
    beacons = createBeacons()
    app = wx.App()
    frame = wx.Frame(None, title='Photo Control')
    #self.frame.ShowFullScreen(True)
    frame.Maximize(True)
    panel = Map(frame)
    panel.beacons = beacons
    panel.refresh()
    time.sleep(1)
    panel.beacons = [beacons[0], beacons[1]]
    panel.refresh()
    frame.Show()
    app.MainLoop()

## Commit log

2018-10-20 added GPS schematic and beginning of beacon schematic
    [Adafruit Ultimate GPS.brd, Adafruit Ultimate GPS.sch, beacon1.sch]
2018-10-20 added atmega 2560 to schematic
    [beacon1.sch]
2018-10-20 made it pretty with notes
    [beacon1.sch]
2018-10-20 changed net names to fix errors
    [beacon1.sch]
2018-10-21 made board, really basic unrouted
    [beacon1.brd]
2018-10-21 added bluetooth chip and condensed layout somewhat, still not routed
    [Adafruit Bluefruit LE UART Friend.brd, Adafruit Bluefruit LE UART Friend.sch, beacon1.brd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]
2018-10-22 added flash chip and made text formal/pretty
    [Adafruit I2C FRAM.brd, Adafruit I2C FRAM.sch, Adafruit SPI FRAM.brd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]
2018-10-22 unrouted, spaced out baoard
    [beacon1.sch]
2018-10-22 redid layout, might be better for routing?
    [beacon1.brd]
2018-10-23 almost 100% routed, but with a lot of gross vias
    [beacon1.brd]
2018-10-23 save before leaving for meeting
    [beacon1.brd, beacon1.sch]
2018-11-11 changed file structure, different folders for each piece of software
    [Adafruit Bluefruit LE UART Friend.brd, Adafruit Bluefruit LE UART Friend.sch, Adafruit I2C FRAM.brd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]
2018-11-28 i changed everything and only just comitted now cause im bad
    [877A-2.DSN, 877acus.xls, Adafruit USB LiIon-LiPoly Charger.brd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]
2018-12-08 removed full ftdi chip, reset board
    [beacon1.brd, beacon1.sch, ftdifriend.brd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]
2019-01-14 final board design
    [Adafruit Verter TPS63060 2A BoostBuck.brd, Adafruit Verter TPS63060 2A BoostBuck.sch, beacon1.brd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]
2019-01-15 made schematic pretty
    [beacon1.sch]
2019-02-14 started main station in python, beacon w/ bluetooth & GPS, currently not working :/
    [GPSMap.py, GUI.py, alert.py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]
2019-02-22 schematic for no breakouts, added basic board layout
    [PCB18059Nicole.brd, PCB18059Nicole.sch]
2019-03-03 finished board, changed sd card pwr
    [PCBFORNICOLESAVE.brd, PCBFORNICOLESAVE.sch]
2019-03-12 removed GPS pps line
    [PCBFORNICOLESAVE.brd]
2019-03-12 removed sd_gnd traces
    [PCBFORNICOLESAVE.brd]
2019-03-12 removed GPS PPS again lol
    [PCBFORNICOLESAVE.sch]
2019-03-14 removed GPS pps (again)
    [PCBFORNICOLESAVE.brd, PCBFORNICOLESAVE.sch]
2019-03-14 finished routing, fixed DRC errors and wire stubs, moved components to make soldering easier
    [PCBFORNICOLESAVE.brd, PCBFORNICOLESAVE.sch]
2019-03-14 rerouted sd card slightly to fix mistake
    [PCBFORNICOLESAVE.brd, PCBFORNICOLESAVE.sch]
2019-03-15 fixed sd card mosfet
    [PCBFORNICOLESAVE.brd, PCBFORNICOLESAVE.sch]
2019-04-01 xbee stuff? might work, unable to test w/ xbees atm, pin issues
    [beacon.ino]
2019-04-02 fixed to read correct indices of ble buffer
    [beacon.ino]
2019-04-06 added nicole's final board to the repo
    [PCBFORNICOLESAVE (2).sch, PCBFORNICOLESAVE.brd]
2019-04-06 name change
    [PCBFORNICOLESAVE.sch]
2019-04-06 deleted timerOne stuff

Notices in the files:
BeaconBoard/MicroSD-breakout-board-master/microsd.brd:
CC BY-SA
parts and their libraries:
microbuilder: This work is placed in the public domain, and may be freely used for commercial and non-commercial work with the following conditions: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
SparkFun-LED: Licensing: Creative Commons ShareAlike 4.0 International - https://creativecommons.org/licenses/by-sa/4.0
